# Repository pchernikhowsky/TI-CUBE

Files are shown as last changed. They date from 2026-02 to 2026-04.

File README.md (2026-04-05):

# The TI CUBE

The `TI CUBE` is a homebrew microcomputer I designed around the Texas Instruments TMS 9900 microprocessor and its associated peripheral devices.

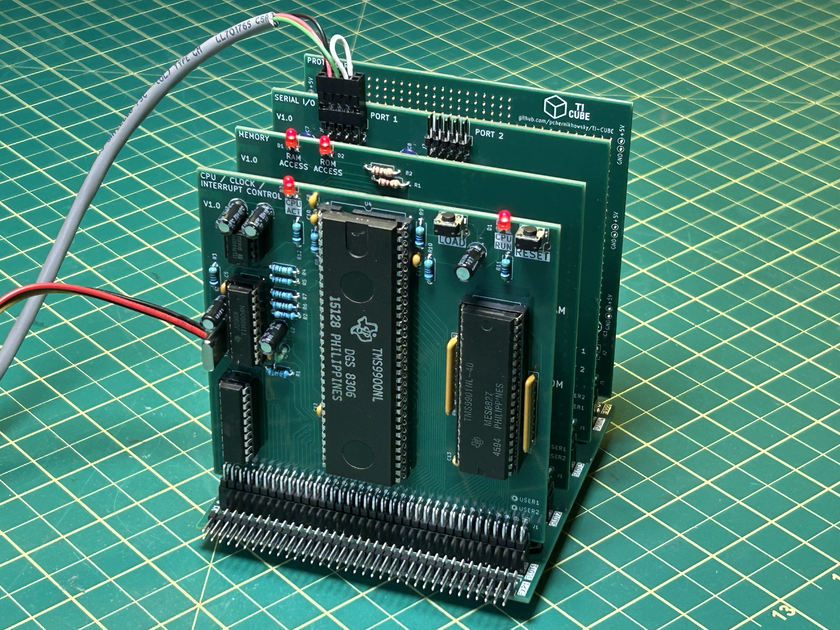
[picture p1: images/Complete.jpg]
Photo of the complete TI CUBE assembly


In its basic form the `TI CUBE` supports communications through two serial ports and has 32 KiB of ROM and 32 KiB of RAM for code and data storage.

# Why the TMS 9900?

The [TMS 9900 microprocessor was relatively advanced for its time (released in 1976)](https://www.cpushack.com/2015/02/05/ti-tms9900sbp9900-accidental-success/) and is essentially a single-chip version of TI's 990 series of 16-bit minicomputers from the 1970s. The TMS 9900 is considered one of the first true 16-bit microprocessors with a full 16-bit external data bus. This was allowed by the use of rather unconventional 64-pin DIP package. The address bus uses 15 bits, but since all memory accesses are 16-bits wide, this provides a 64 KiB address space (32 K of 16 bit words). The most unique feature of the TMS 9900 is that it had no internal registers, other than PC (program counter), WP (workspace pointer), and status register (SR) - all 16-bits wide. Instead of internal registers, the WP pointed to a region in external memory where 16 "registers" were stored in sequential memory addresses. Adjusting the WP allowed for very fast context switching by pointing to a different set of "registers". This capability was used in TI 990 minicomputers to support multiuser computing.

The elegance of the true 16-bit data bus (unlike the crippled Intel 8088 CPU used in the first IBM PC) and the quirkiness of its memory-based registers makes this chip a fascinating way to explore early microcomputer technology and its capabilities.

Finally, the project was greatly inspired by [Usagi Electric](https://www.youtube.com/@UsagiElectric)'s ongoing homebrew computer project based on the TMS 9900 CPU. I had a spare TMS 9900 IC that I removed from a TI-99/4A several decades ago(!), and figured this was a good way to put it to use. 

# Design Philosophy

The following principles guided my development of this homebrew project. The list is roughly in order of priority (highest is first).

1. **No 8-bit data buses!** The TMS 9900 microprocessor is fundamentally a 16-bit design descendent from TI's 990 series of 16-bit minicomputers and I wanted to honour this ancestry as much as possible. I find address/data bus muxing/demuxing unsightly, complex, and inelegant. Yes, the TMS 9900 isn't the fastest of the TMS 99XX series of microprocessors, but it's the only one that supports an *external* 16-bit data bus interface.

2. **Modularity.** Just like a minicomputer which would typically have a backplane populated with multiple cards, the `TI CUBE` uses a similar philosophy with three basic cards: 
   * CPU card (with clock and interrupt control)
   * Memory card (holding the RAM and ROM)
   * Serial port interface card (equipped with two serial chips driving two EIA-232C compatible ports). 
  
   All cards plug into a backplane using 72-pin header connectors. Any card can go in any slot, and multiple cards (e.g., multiple seial interface cards) are supported. Additional backplanes can also be daisy-chained to support additional card slots. The expansion connectors (especially the pin header connector) also makes for handy connections to bus signals for debugging (via a scope or logic analyzer).

3. **Board size.** Constraining the board size to 100 x 100 mm (4 x 4 in) allows ordering PCBs using the [JLCPCB](https://jlcpcb.com) or [PCBWAY](https://pcbway.com) prototyping services (personally, I have had great experience with JLCPCB). This significantly reduces the cost of individual boards (approximately $2 per board). The physical construction also gives the `TI CUBE` its name: four 100 x 100 mm vertical cards plugged into a horizontal four-slot 100 x 100 mm backplane.

4. **Simplicity.** I subscribe to the [Earl Muntz](https://en.wikipedia.org/wiki/Muntzing) philosophy. As such, the `TI CUBE` design uses the minimum required amount of components to accomplish its function. Random logic (i.e., TTL gates and decoders) is complex and consumes significant board space. Instead, I prefer to use simple and standard PLD devices like the ubiquitous 16V8, which does everything needed in one chip.[^4] This also allows easily reconfigurability simply by reprogramming the PLD. There are  no address or data buffers in the `TI CUBE`, but the small size combined with the use of four-layer PCBs keeps the digital signals clean; my builds have demonstrated excellent reliablity and performance. 

5. **Period correctness.** Primarily this means use of only through-hole components (no surface mount). I don't mind SMD as such, but through-hole is still easier to assemble and is more typical of 70s/80s computers. I have violated the period-correctness rule in number of other places (e.g., use of PLDs instead of random logic, larger memory ICs compared to what was available in the 70s and early 80s), so this one is more a [guideline than an actual rule](https://www.youtube.com/watch?v=omjnIeLIzJc&t=13s). 😉
   
8. **Compatibility.** I designed the `TI CUBE` to be generally compatible with other TMS 9900-based systems. One example is [Stuart Connor's TMS 9900 breadboard/PCB system](http://www.stuartconner.me.uk/tms9900_breadboard/tms9900_breadboard.htm). In fact, the binary files he provides can be downloaded, burned to EPROMs, and used directly in the `TI CUBE`. This includes the TIBUG monitor and Cortex BASIC which work right out of the box!

# Hardware Specifications

1. **CPU board** [(photo)](images/CPU.jpg)
-  TMS 9900 microprocessor running at 3 MHz[^1]
-  TIM 9904 or TIM 9904A clock generator[^2]
-  TMS 9901 programmable systems interface (PSI) for interrupt management
-  ATF16V8 PLD for address decoding
-  ICL7660 voltage convertor to generate the -5V power supply needed by the CPU
-  2x red LEDs for CPU RESET signal and CPU activity (driven by the IAQ output) indication
2. **Memory board** [(photo)](images/Memory.jpg)
-  2x EPROMs (e.g., 2764, 27128, 27256) for 32 KiB of EPROM[^3]
-  2x static RAM (e.g., 55256) for 32 KiB of RAM[^3]
-  2x red LEDs for RAM and ROM access indication
-  ATF16V8 PLD for address decoding
-  Jumpers to control use of the EPROM A14 address line (or to select the high or low bank)
3. **Serial I/O board** [(photo)](images/Serial_IO.jpg)
-  2x TMS 9902 asynchronous communications controllers (ACC)
-  2x MAX232 interfaces for EIA-232C compatible serial ports
-  2x ATF16V8 PLD for address decoding
-  2x 10-pin 0.1 in header connectors using the AT/Everex standard pinout to connect serial devices
-  Jumpers to allow address and interrupt selection for each TMS 9902
4. **Protoboard** [(photo)](images/Protoboard.jpg)
-  Unpopulated PCB with a large area of plated-through holes for prototyping
-  Optional ATF16V8 PLD for address decoding
5. **Backplane** [(photo)](images/Backplane.jpg)
-  4x 72-pin header sockets which support any combination of the cards above
-  1x 72-pin header socket for daisy chaining multiple backplanes
-  1x 72-pin header pin connector for daisy chaining multiple backplanes
-  2x red LEDs for +5V and +12 power supply indication
-  1x 4-pin Berg connector for +5V and +12V power supplies (compatible with a standard 3.5 in floppy power connector)

# Future Expansion/Ideas

## External Instructions
The TMS 9900 has an interesting feature where a handful of instructions can be decoded external and used to trigger various hardware functions. These instructions are:

## RAM Memory Expansion
The base system memory board decodes the entire address space of the TMS 9900, but this is a maximum of 65536 bytes (64 kiB). A number of other computers based on the TMS 9900 (e.g., Cortex and the TI 990/10 and 990/12) used memory mappers to expand the memory space up to 1 MiB or more of RAM. The primary advantage of this expansion is that would allow running either [MDEX](http://www.stuartconner.me.uk/mini_cortex/mini_cortex.htm#using_mdex) or [Unix](http://www.stuartconner.me.uk/mini_cortex/mini_cortex.htm#using_unix), both courtesy of Stuart Conner. I'd really like to try this as it might allow a rudimentary mulituser system when equipped with multiple additional serial cards. 

## Floppy and/or Hard Drive Controller

# Notes

[^1]: Overclocking to 4 MHz is possible if a TMS 9900-40 CPU is used and the appropriate clock component changes are made.

[^2]: Depending on whether the TIM 9904 or TIM 9904A is used, and which CPU frequency is desired (12 or 16 MHz) different components must be selected for the clock crystal and tank circuit. A table of values is provided in the CPU schematic.

[^3]: The RAM and ROM sizes can be adjusted in any combination that fits within the 64KB address space simply by adjusting the logic for the chip enable outputs in the PLD program.

[^4]: The use of PLDs does mean that you need a programmer (such as the [XGecu TL866II Plus](http://autoelectric.cn/EN/TL866_main.html), or similar). What, you don't have one? Then get one - they're super handy for retrocomputing.

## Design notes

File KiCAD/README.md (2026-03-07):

# TI Cube schematics and PCB design files

These folders contain the schematic and PCB design files for the four cards and backplane.

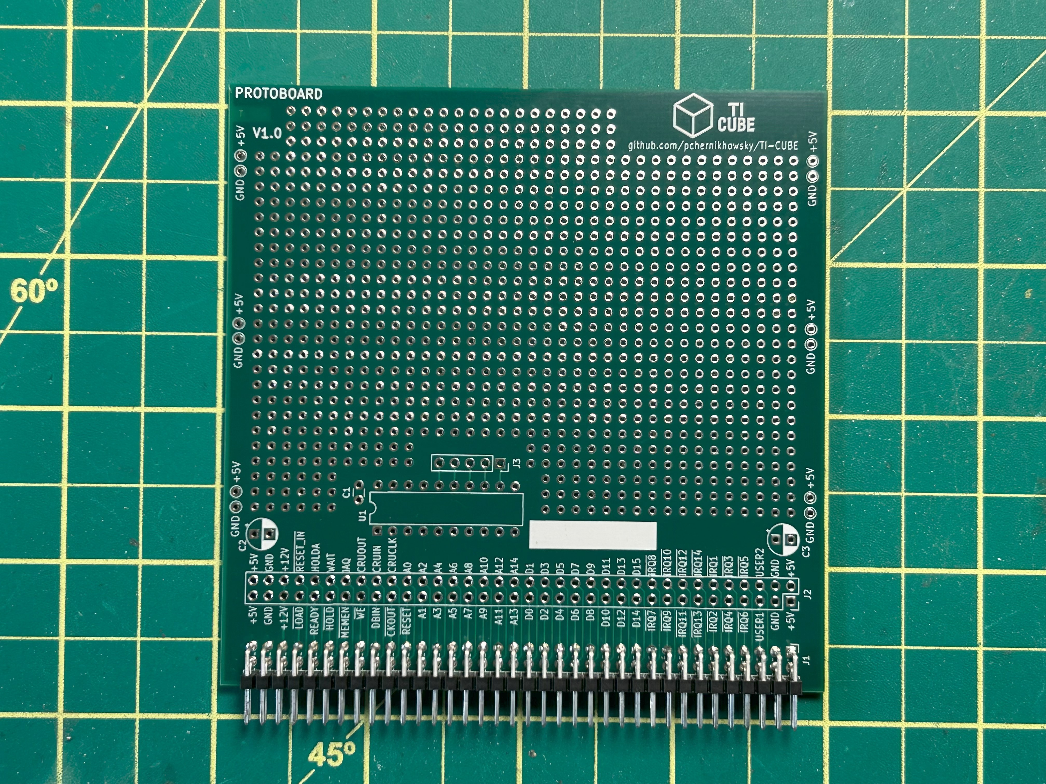
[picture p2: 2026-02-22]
images/Protoboard.jpg

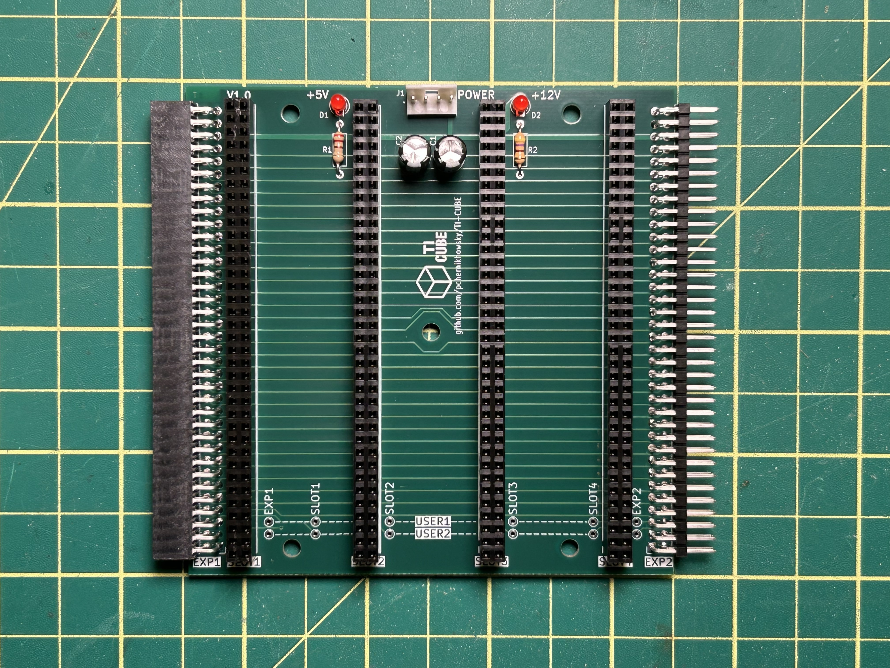
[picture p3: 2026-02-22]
images/Backplane.jpg

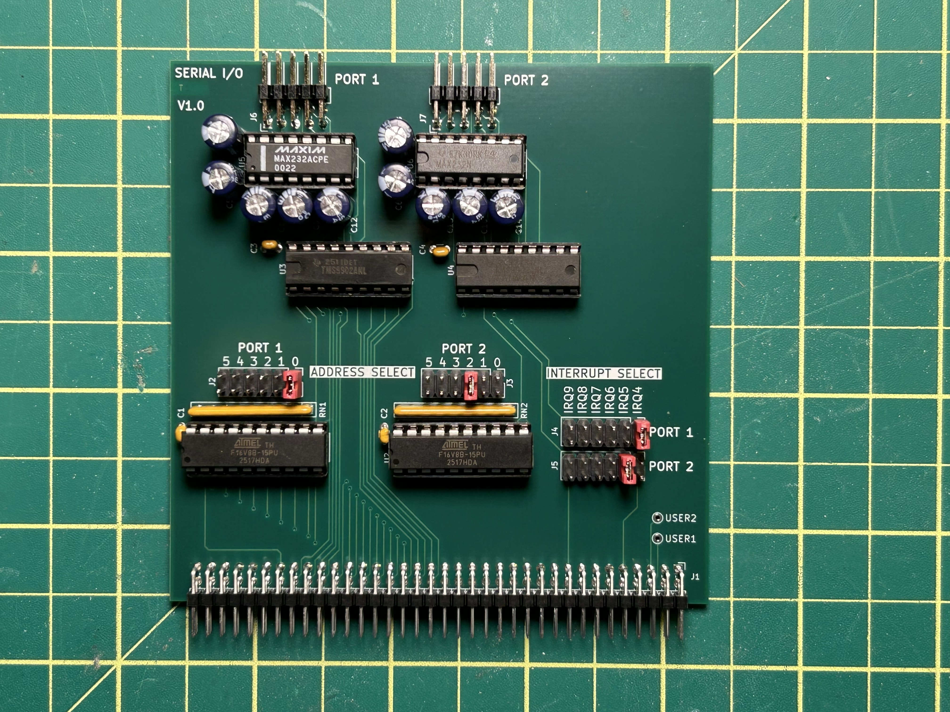
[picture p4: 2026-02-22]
images/Serial_IO.jpg

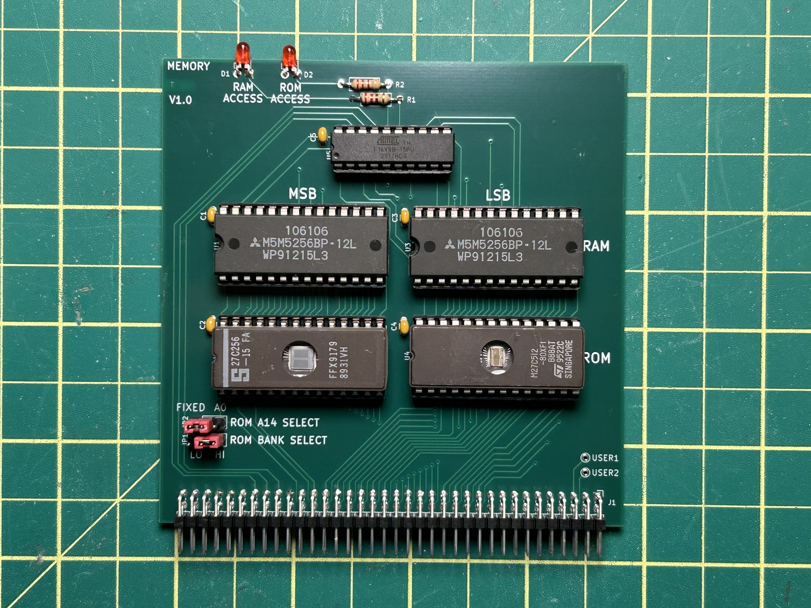
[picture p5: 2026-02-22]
images/Memory.jpg

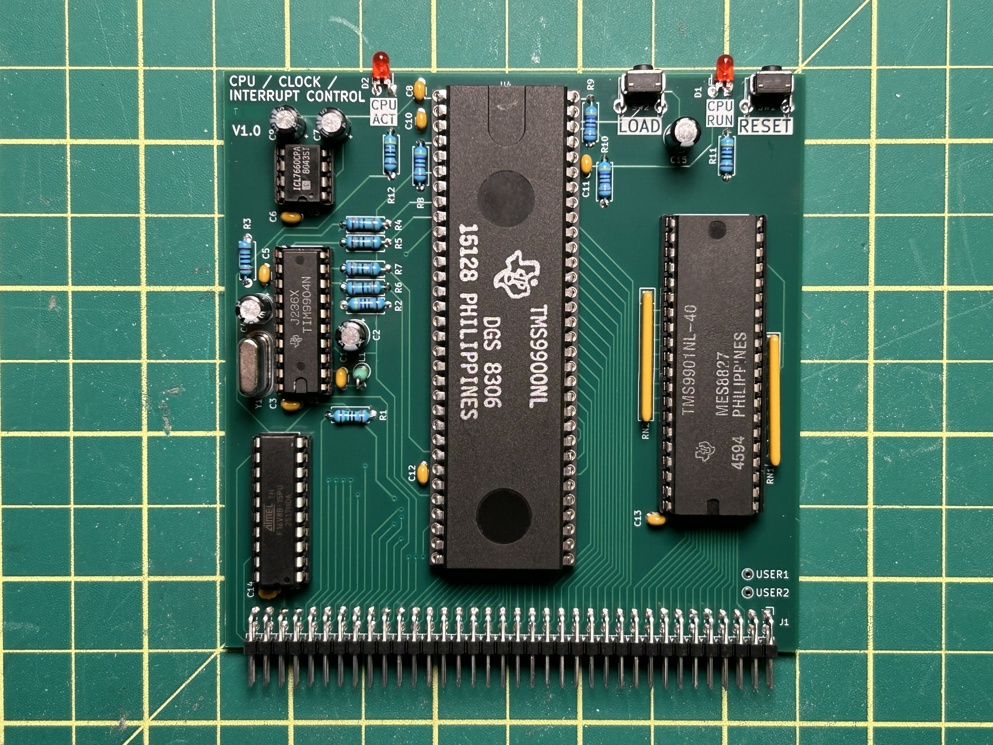
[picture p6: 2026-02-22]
images/CPU.jpg

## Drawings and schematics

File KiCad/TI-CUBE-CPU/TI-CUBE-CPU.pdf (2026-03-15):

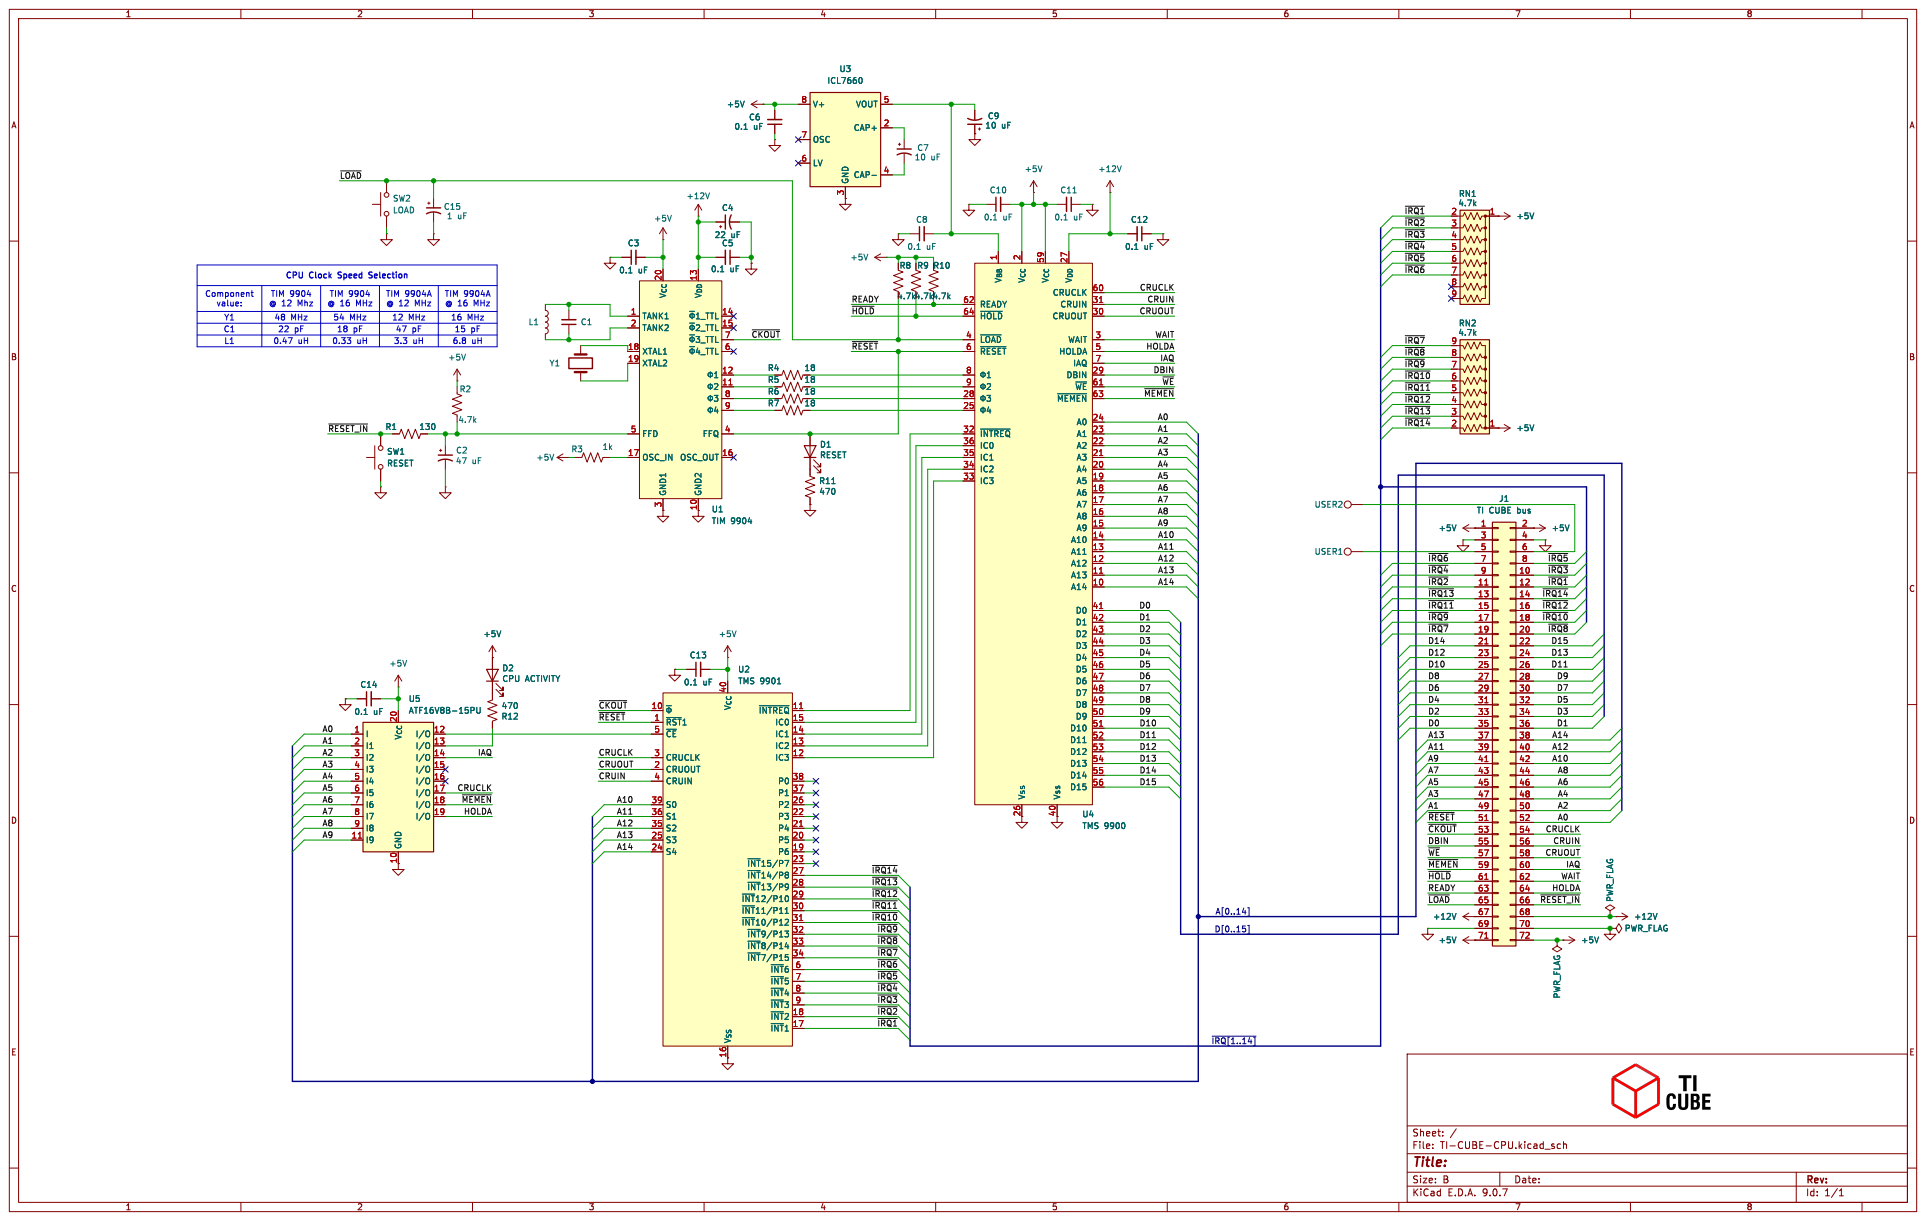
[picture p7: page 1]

Id: 1/1 Title: File: TI-CUBE-CPU.kicad_sch Sheet: /

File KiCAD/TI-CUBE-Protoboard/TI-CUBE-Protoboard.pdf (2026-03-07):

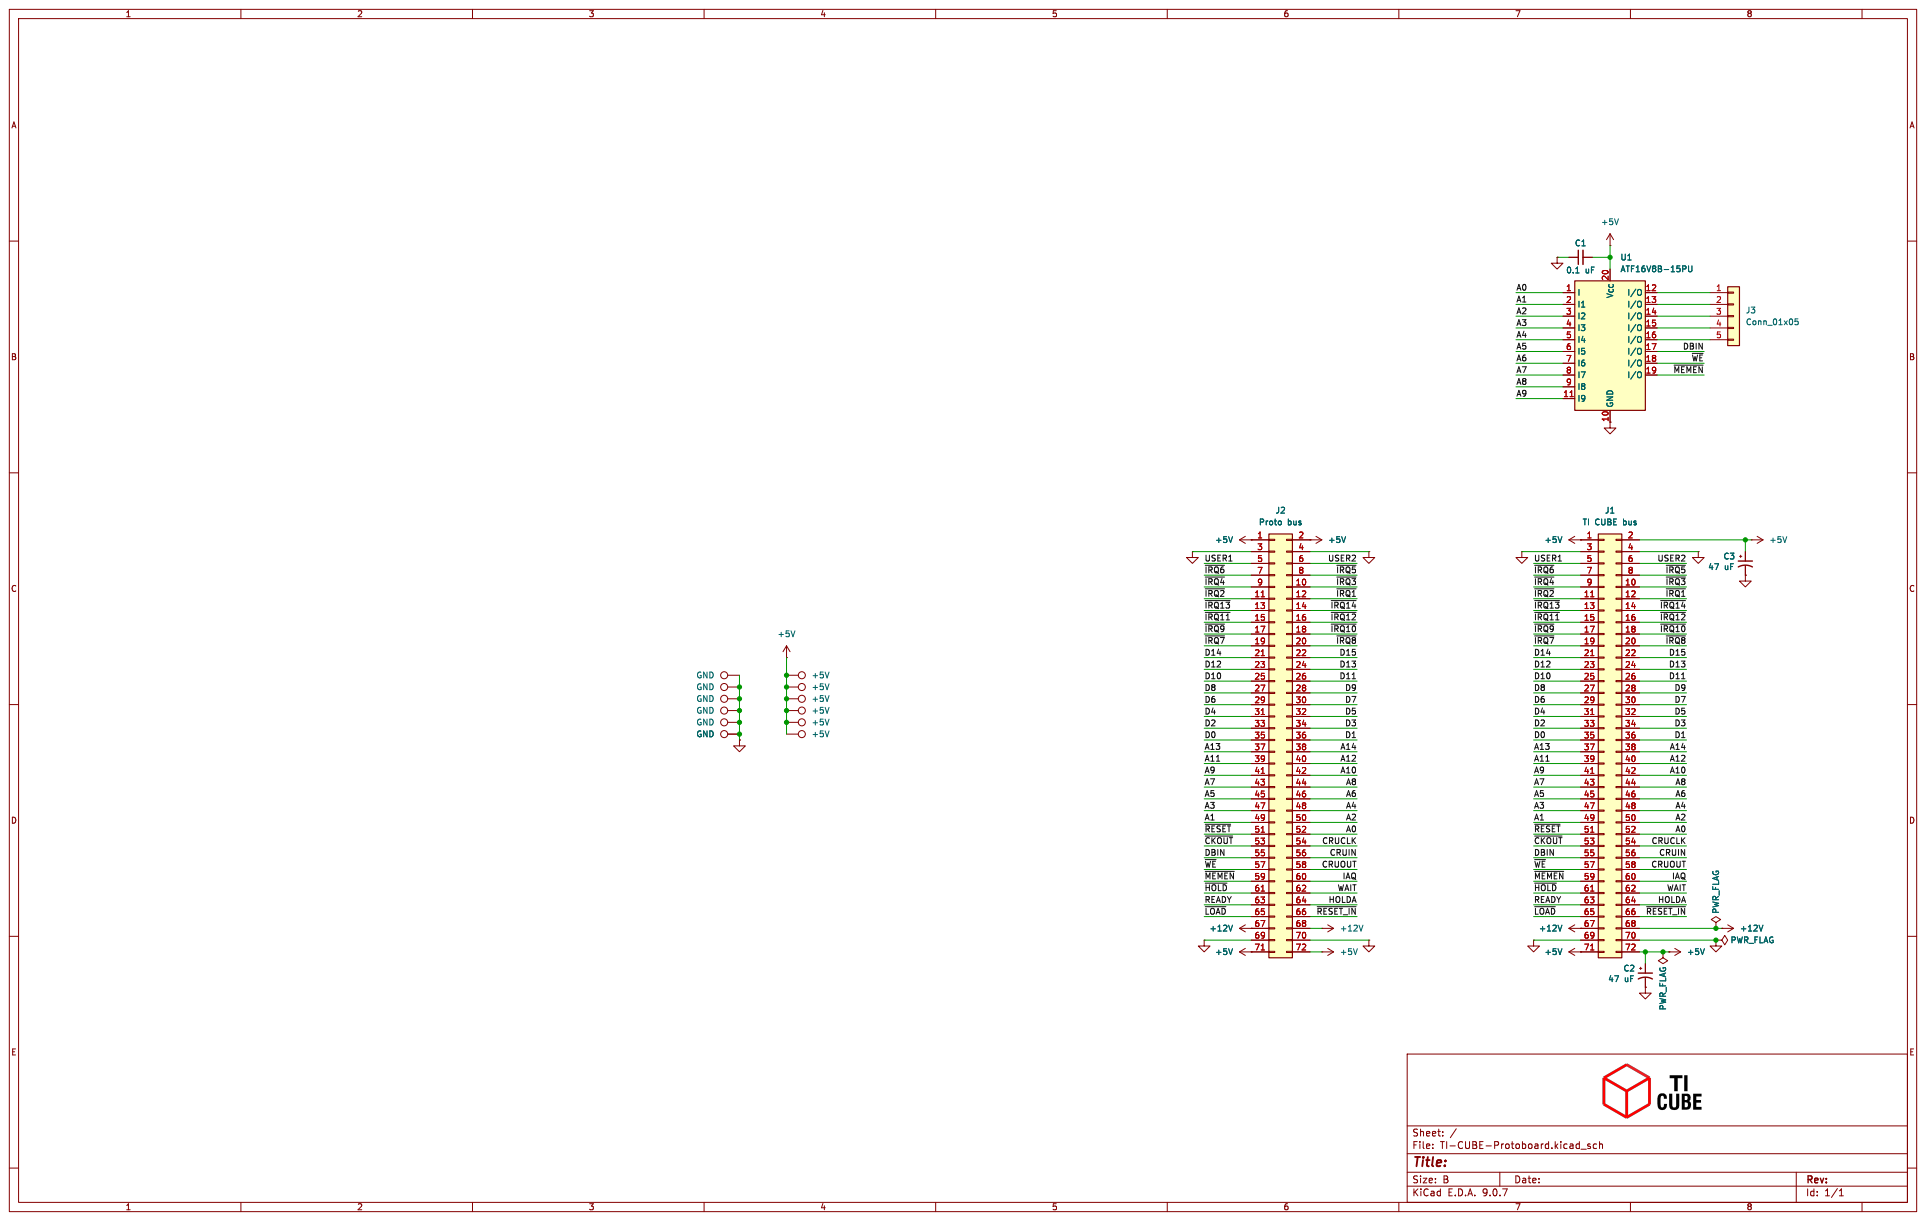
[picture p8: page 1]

Id: 1/1 Title: File: TI-CUBE-Protoboard.kicad_sch Sheet: / GND

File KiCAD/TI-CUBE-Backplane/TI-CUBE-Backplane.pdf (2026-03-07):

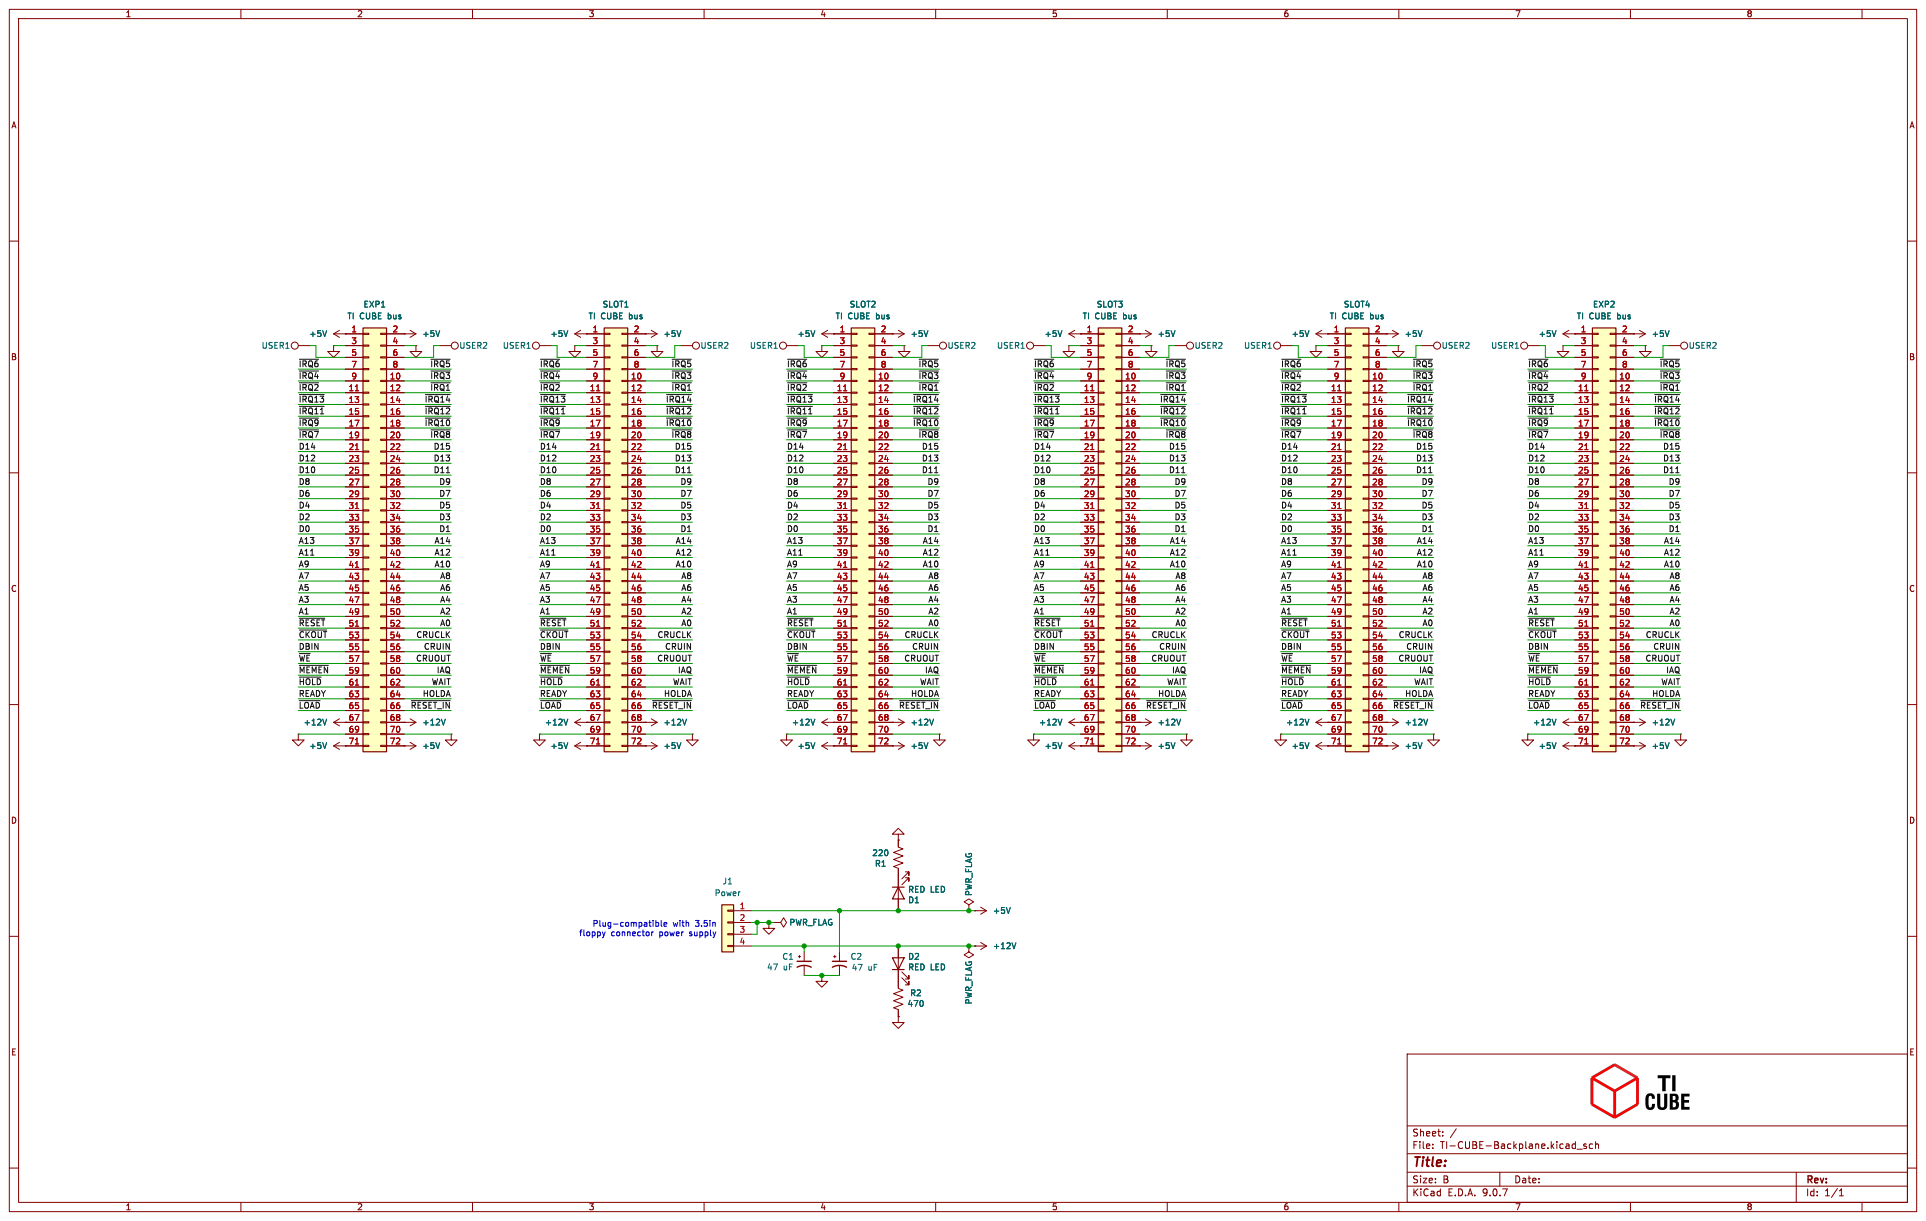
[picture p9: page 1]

Id: 1/1 Title: File: TI-CUBE-Backplane.kicad_sch Sheet: / C1

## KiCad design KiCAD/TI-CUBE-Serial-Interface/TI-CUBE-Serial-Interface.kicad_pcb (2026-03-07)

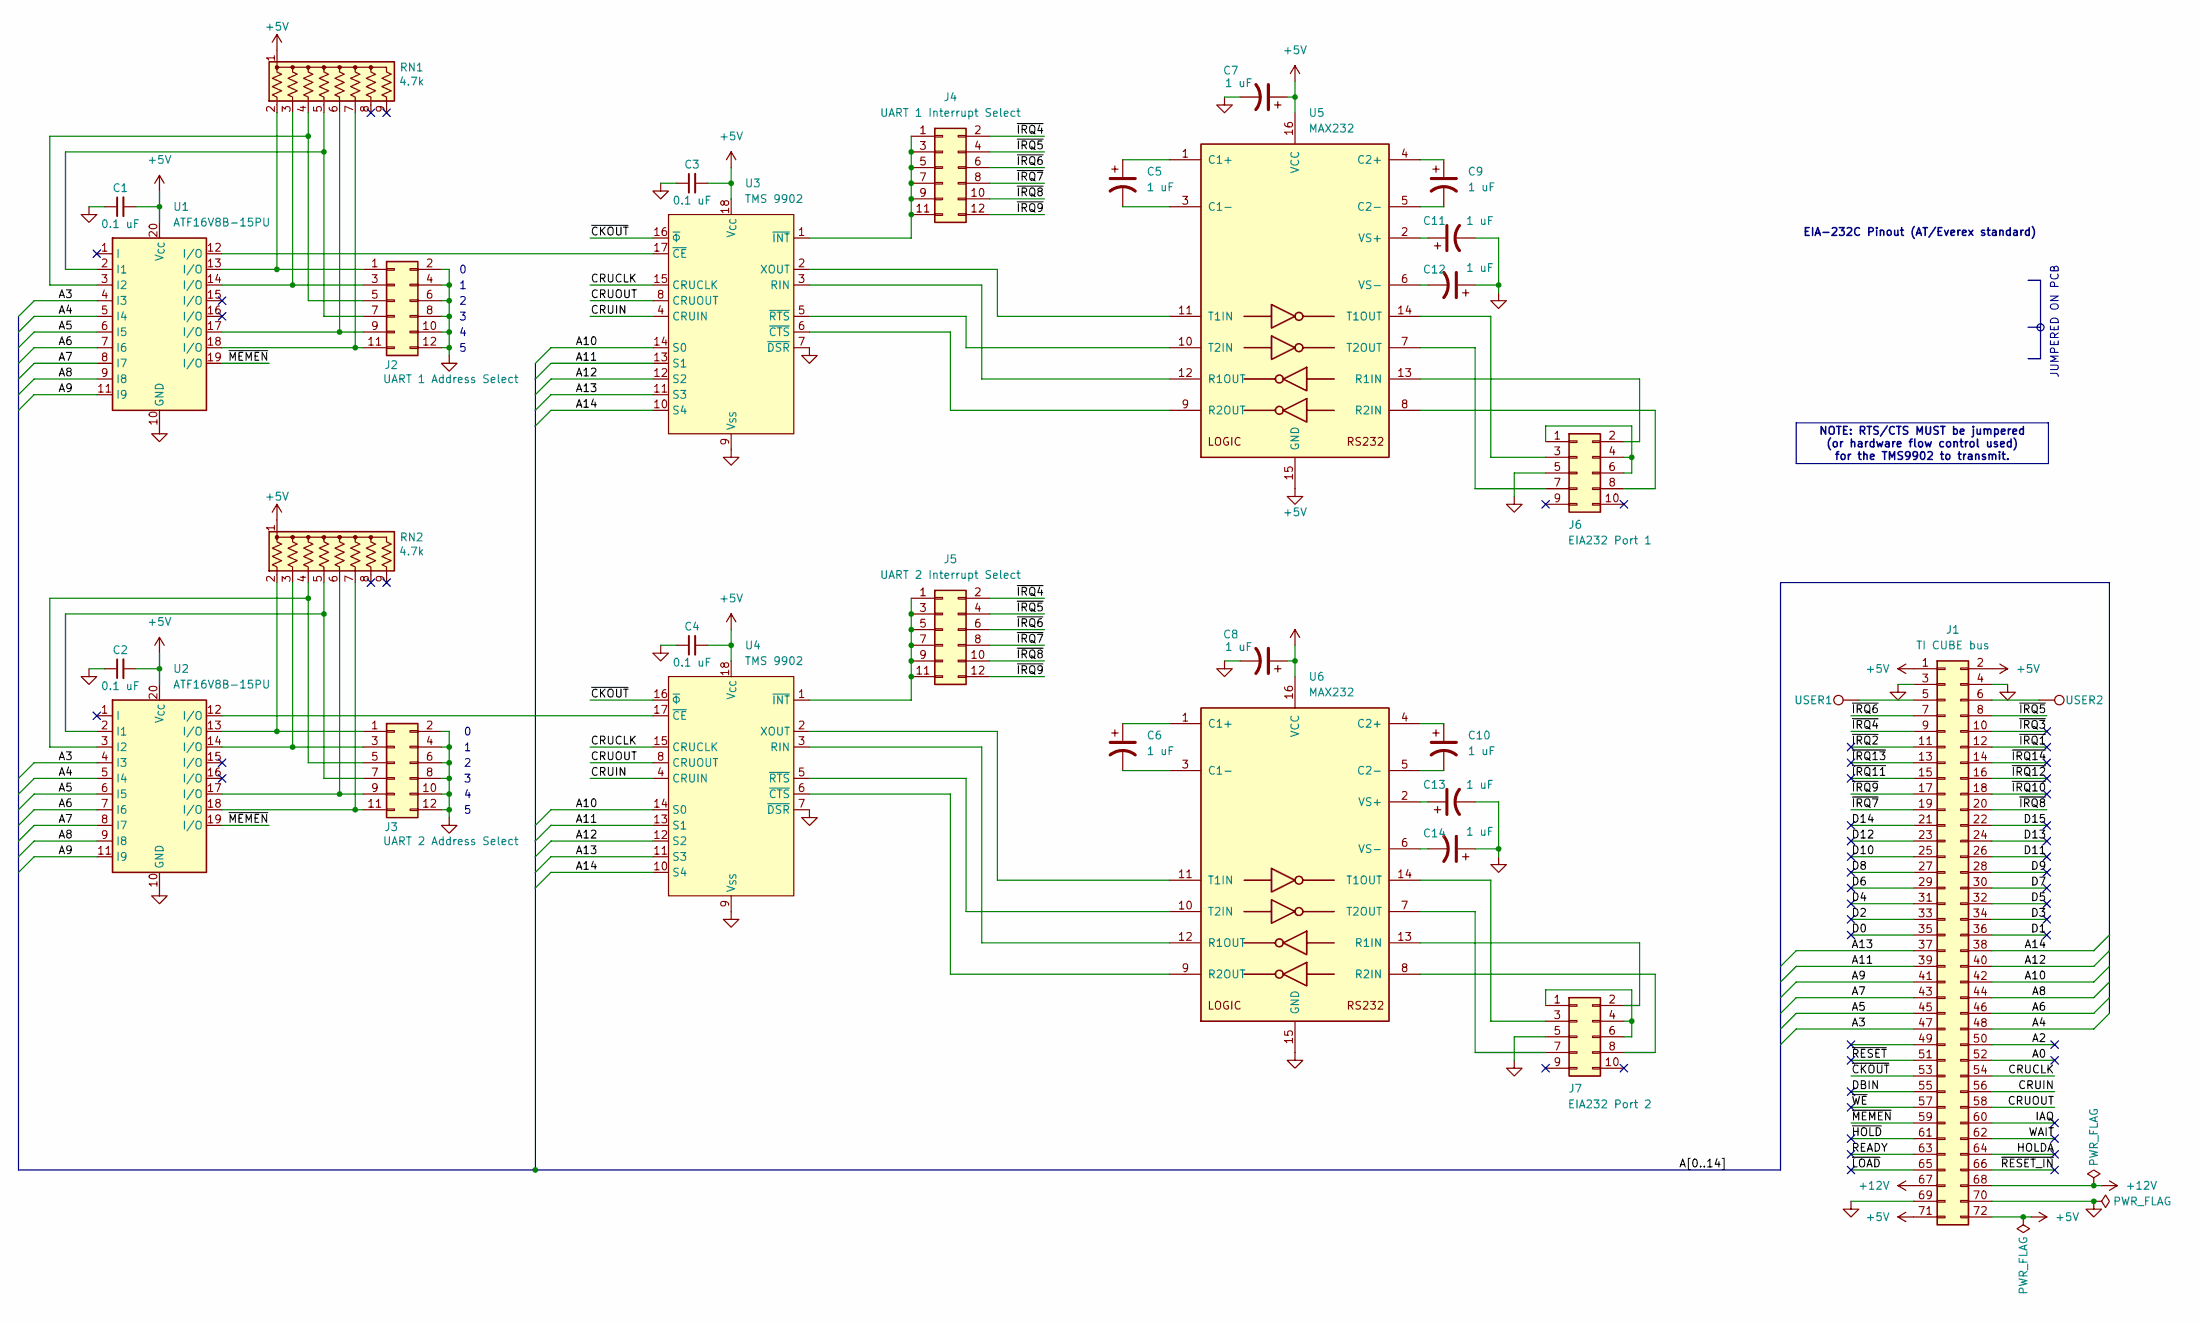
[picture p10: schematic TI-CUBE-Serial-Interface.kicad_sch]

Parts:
C1, C2, C3, C4: 0.1 uF; C_Ceramic_Cap_P2.50mm
C5, C6, C7, C8, C9, C10, C11, C12, C13, C14: 1 uF; CP_Radial_D5.0mm_P2.50mm
J1: TI CUBE bus; PinHeader_2x36_P2.54mm_Horizontal
J2: UART 1 Address Select; PinHeader_2x06_P2.54mm_Vertical
J3: UART 2 Address Select; PinHeader_2x06_P2.54mm_Vertical
J4: UART 1 Interrupt Select; PinHeader_2x06_P2.54mm_Vertical
J5: UART 2 Interrupt Select; PinHeader_2x06_P2.54mm_Vertical
J6: EIA232 Port 1; PinHeader_2x05_P2.54mm_Horizontal
J7: EIA232 Port 2; PinHeader_2x05_P2.54mm_Horizontal
RN1, RN2: 4.7k; R_Array_SIP9
U1, U2: ATF16V8B-15PU; DIP-20_W7.62mm
U3, U4: TMS 9902; DIP-18_W7.62mm
U5, U6: MAX232; DIP-16_W7.62mm
USER1: USER2; TestPoint_THTPad_D1.5mm_Drill0.7mm
USER2: USER1; TestPoint_THTPad_D1.5mm_Drill0.7mm

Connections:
+5V: C1.2, C2.2, C3.2, C4.2, C7.1, C8.1, J1.1, J1.2, J1.71, J1.72, RN1.1 (common), RN2.1 (common), U1.20 (V_{CC}), U2.20 (V_{CC}), U3.18 (V_{CC}), U4.18 (V_{CC}), U5.16 (VCC), U6.16 (VCC)
+12V: J1.67, J1.68
/A0: J1.52
/A2: J1.50
/A3: J1.47, U1.4 (I3), U2.4 (I3)
/A4: J1.48, U1.5 (I4), U2.5 (I4)
/A5: J1.45, U1.6 (I5), U2.6 (I5)
/A6: J1.46, U1.7 (I6), U2.7 (I6)
/A7: J1.43, U1.8 (I7), U2.8 (I7)
/A8: J1.44, U1.9 (I8), U2.9 (I8)
/A9: J1.41, U1.11 (I9), U2.11 (I9)
/A10: J1.42, U3.14 (S0), U4.14 (S0)
/A11: J1.39, U3.13 (S1), U4.13 (S1)
/A12: J1.40, U3.12 (S2), U4.12 (S2)
/A13: J1.37, U3.11 (S3), U4.11 (S3)
/A14: J1.38, U3.10 (S4), U4.10 (S4)
/CRUCLK: J1.54, U3.15 (CRUCLK), U4.15 (CRUCLK)
/CRUIN: J1.56, U3.4 (CRUIN), U4.4 (CRUIN)
/CRUOUT: J1.58, U3.8 (CRUOUT), U4.8 (CRUOUT)
/D0: J1.35
/D1: J1.36
/D2: J1.33
/D3: J1.34
/D4: J1.31
/D5: J1.32
/D6: J1.29
/D7: J1.30
/D8: J1.27
/D9: J1.28
/D10: J1.25
/D11: J1.26
/D12: J1.23
/D13: J1.24
/D14: J1.21
/D15: J1.22
/DBIN: J1.55
/HOLDA: J1.64
/IAQ: J1.60
/READY: J1.63
/WAIT: J1.62
/~CKOUT: J1.53, U3.16 (~Φ), U4.16 (~Φ)
/~HOLD: J1.61
/~IRQ1: J1.12
/~IRQ2: J1.11
/~IRQ3: J1.10
/~IRQ4: J1.9, J4.2, J5.2
/~IRQ5: J1.8, J4.4, J5.4
/~IRQ6: J1.7, J4.6, J5.6
/~IRQ7: J1.19, J4.8, J5.8
/~IRQ8: J1.20, J4.10, J5.10
/~IRQ9: J1.17, J4.12, J5.12
/~IRQ10: J1.18
/~IRQ11: J1.15
/~IRQ12: J1.16
/~IRQ13: J1.13
/~IRQ14: J1.14
/~LOAD: J1.65
/~MEMEN: J1.59, U1.19 (I/O), U2.19 (I/O)
/~RESET_IN: J1.66
/~RESET: J1.51
/~WE: J1.57
GND: C1.1, C2.1, C3.1, C4.1, C7.2, C8.2, C11.2, C12.1, C13.2, C14.1, J1.3, J1.4, J1.69, J1.70, J2.2, J2.4, J2.6, J2.8, J2.10, J2.12, J3.2, J3.4, J3.6, J3.8, J3.10, J3.12, J6.5, J7.5, U1.10 (GND), U2.10 (GND), U3.7 (~DSR), U3.9 (V_{SS}), U4.7 (~DSR), U4.9 (V_{SS}), U5.15 (GND), U6.15 (GND)
unnamed: J1.5, USER2.1
unnamed: J1.6, USER1.1
unnamed: J2.1, RN1.2 (R1), U1.13 (I/O)
unnamed: J2.3, RN1.3 (R2), U1.14 (I/O)
unnamed: J2.5, RN1.4 (R3), U1.3 (I2)
unnamed: J2.7, RN1.5 (R4), U1.2 (I1)
unnamed: J2.9, RN1.6 (R5), U1.17 (I/O)
unnamed: J2.11, RN1.7 (R6), U1.18 (I/O)
unnamed: J3.1, RN2.2 (R1), U2.13 (I/O)
unnamed: J3.3, RN2.3 (R2), U2.14 (I/O)
unnamed: J3.5, RN2.4 (R3), U2.3 (I2)
unnamed: J3.7, RN2.5 (R4), U2.2 (I1)
unnamed: J3.9, RN2.6 (R5), U2.17 (I/O)
unnamed: J3.11, RN2.7 (R6), U2.18 (I/O)
unnamed: J4.1, J4.3, J4.5, J4.7, J4.9, J4.11, U3.1 (~INT)
unnamed: J5.1, J5.3, J5.5, J5.7, J5.9, J5.11, U4.1 (~INT)
unnamed: J6.1, J6.4, J6.6
unnamed: J6.2, U5.13 (R1IN)
unnamed: J6.3, U5.14 (T1OUT)
unnamed: J6.7, U5.7 (T2OUT)
unnamed: J6.8, U5.8 (R2IN)
unnamed: J7.1, J7.4, J7.6
unnamed: J7.2, U6.13 (R1IN)
unnamed: J7.3, U6.14 (T1OUT)
unnamed: J7.7, U6.7 (T2OUT)
unnamed: J7.8, U6.8 (R2IN)
unnamed: U3.3 (RIN), U5.12 (R1OUT)
unnamed: U3.2 (XOUT), U5.11 (T1IN)
unnamed: U1.12 (I/O), U3.17 (~CE)
unnamed: U3.6 (~CTS), U5.9 (R2OUT)
unnamed: U3.5 (~RTS), U5.10 (T2IN)
unnamed: U4.3 (RIN), U6.12 (R1OUT)
unnamed: U4.2 (XOUT), U6.11 (T1IN)
unnamed: U2.12 (I/O), U4.17 (~CE)
unnamed: U4.6 (~CTS), U6.9 (R2OUT)
unnamed: U4.5 (~RTS), U6.10 (T2IN)
unnamed: C5.1, U5.1 (C1+)
unnamed: C5.2, U5.3 (C1-)
unnamed: C9.1, U5.4 (C2+)
unnamed: C9.2, U5.5 (C2-)
unnamed: C11.1, U5.2 (VS+)
unnamed: C12.2, U5.6 (VS-)
unnamed: C6.1, U6.1 (C1+)
unnamed: C6.2, U6.3 (C1-)
unnamed: C10.1, U6.4 (C2+)
unnamed: C10.2, U6.5 (C2-)
unnamed: C13.1, U6.2 (VS+)
unnamed: C14.2, U6.6 (VS-)

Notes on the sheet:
JUMPERED ON PCB
EIA-232C Pinout (AT/Everex standard)
NOTE: RTS/CTS MUST be jumpered (or hardware flow control used) for the TMS9902 to transmit.

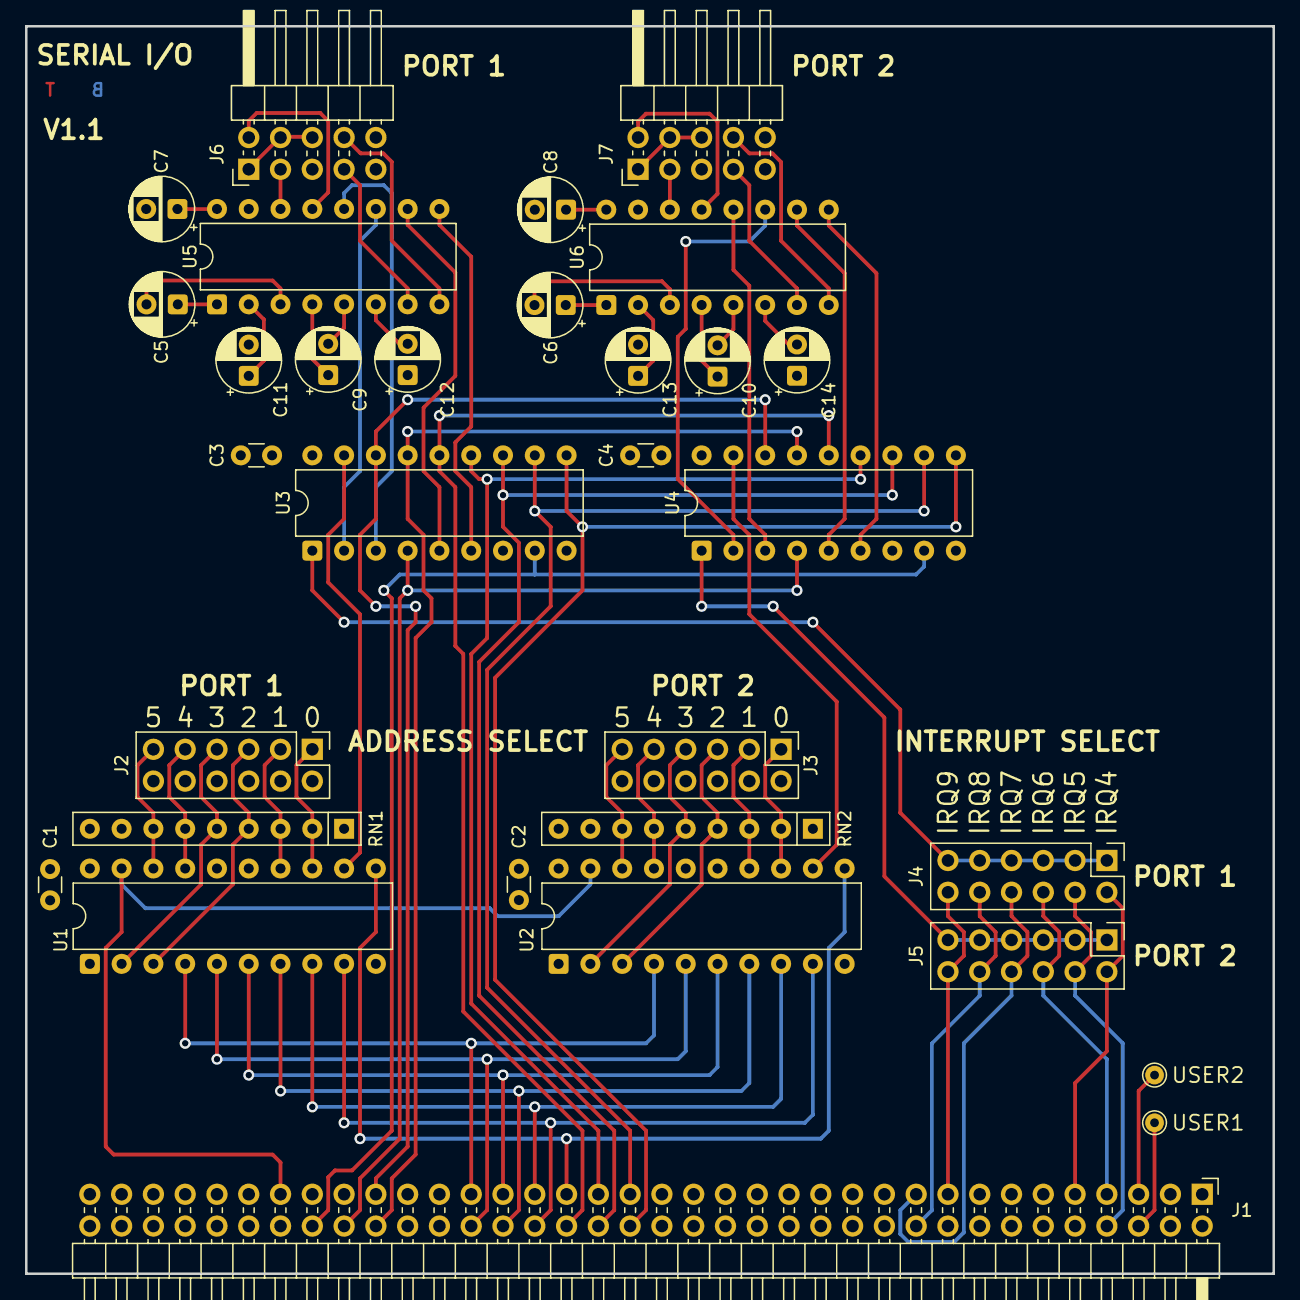
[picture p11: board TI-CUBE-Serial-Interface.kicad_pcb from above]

Board: 4 copper layers, 99.7 x 99.7 mm, 31 parts (0 on the bottom side), 74 nets.

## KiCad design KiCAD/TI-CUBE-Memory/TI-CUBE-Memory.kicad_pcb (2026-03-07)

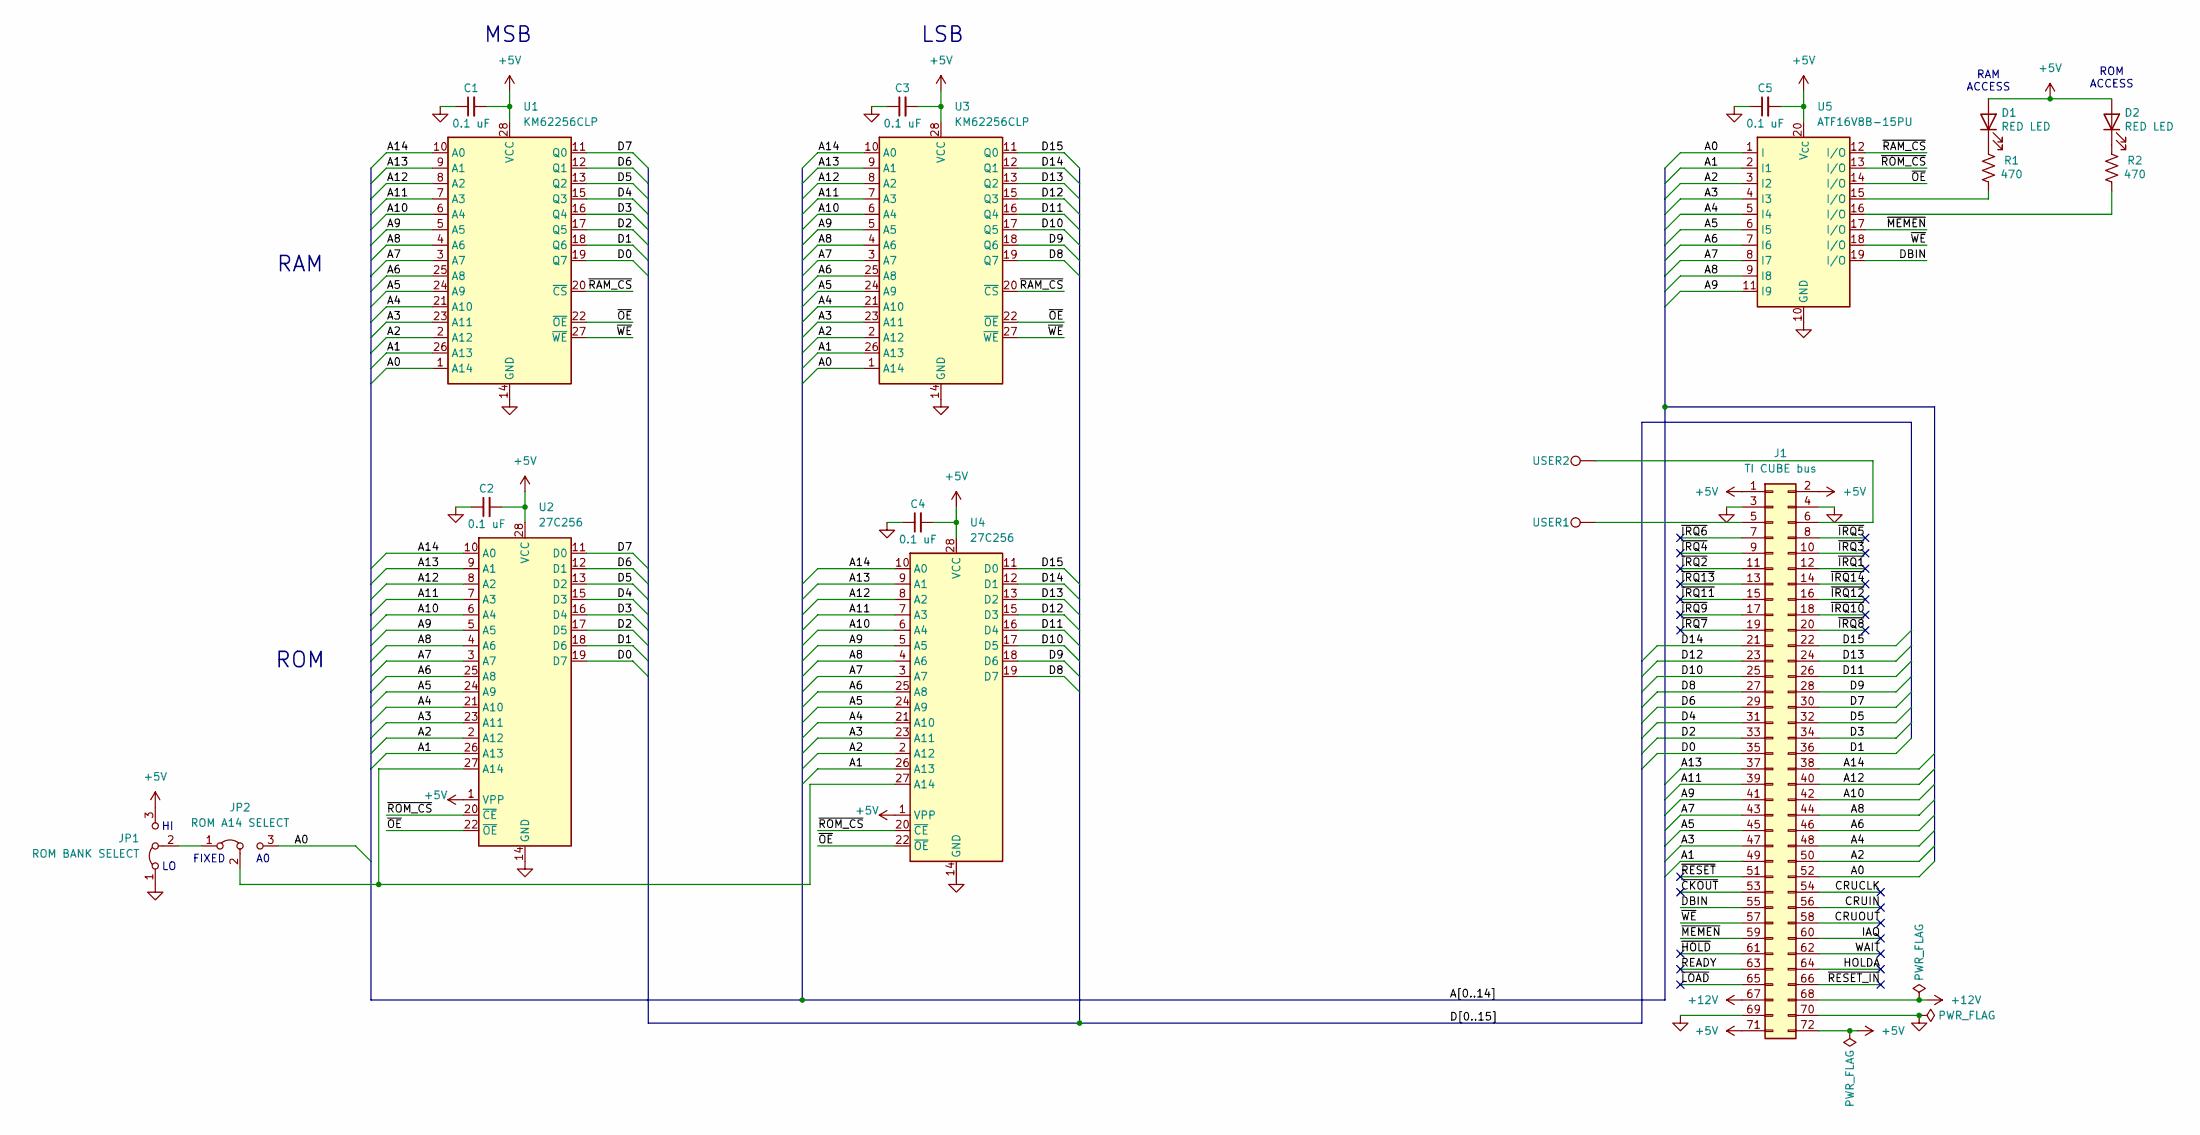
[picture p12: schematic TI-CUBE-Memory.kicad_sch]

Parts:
C1, C2, C3, C4, C5: 0.1 uF; C_Ceramic_Cap_P2.50mm
D1, D2: RED LED; LED_D3.0mm_Horizontal_O1.27mm_Z2.0mm
J1: TI CUBE bus; PinHeader_2x36_P2.54mm_Horizontal
JP1: ROM BANK SELECT; PinHeader_1x03_P2.54mm_Vertical
JP2: ROM A14 SELECT; PinHeader_1x03_P2.54mm_Vertical
R1, R2: 470; R_Axial_DIN0207_L6.3mm_D2.5mm_P10.16mm_Horizontal
U1, U3: KM62256CLP; DIP-28_W15.24mm
U2, U4: 27C256; DIP-28_W15.24mm
U5: ATF16V8B-15PU; DIP-20_W7.62mm
USER1: USER1; TestPoint_THTPad_D1.5mm_Drill0.7mm
USER2: USER2; TestPoint_THTPad_D1.5mm_Drill0.7mm

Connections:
+5V: C1.2, C2.2, C3.2, C4.2, C5.2, D1.2 (A), D2.2 (A), J1.1, J1.2, J1.71, J1.72, JP1.3 (B), U1.28 (VCC), U2.1 (VPP), U2.28 (VCC), U3.28 (VCC), U4.1 (VPP), U4.28 (VCC), U5.20 (V_{CC})
+12V: J1.67, J1.68
/A0: J1.52, JP2.3 (B), U1.1 (A14), U3.1 (A14), U5.1 (I)
/A1: J1.49, U1.26 (A13), U2.26 (A13), U3.26 (A13), U4.26 (A13), U5.2 (I1)
/A2: J1.50, U1.2 (A12), U2.2 (A12), U3.2 (A12), U4.2 (A12), U5.3 (I2)
/A3: J1.47, U1.23 (A11), U2.23 (A11), U3.23 (A11), U4.23 (A11), U5.4 (I3)
/A4: J1.48, U1.21 (A10), U2.21 (A10), U3.21 (A10), U4.21 (A10), U5.5 (I4)
/A5: J1.45, U1.24 (A9), U2.24 (A9), U3.24 (A9), U4.24 (A9), U5.6 (I5)
/A6: J1.46, U1.25 (A8), U2.25 (A8), U3.25 (A8), U4.25 (A8), U5.7 (I6)
/A7: J1.43, U1.3 (A7), U2.3 (A7), U3.3 (A7), U4.3 (A7), U5.8 (I7)
/A8: J1.44, U1.4 (A6), U2.4 (A6), U3.4 (A6), U4.4 (A6), U5.9 (I8)
/A9: J1.41, U1.5 (A5), U2.5 (A5), U3.5 (A5), U4.5 (A5), U5.11 (I9)
/A10: J1.42, U1.6 (A4), U2.6 (A4), U3.6 (A4), U4.6 (A4)
/A11: J1.39, U1.7 (A3), U2.7 (A3), U3.7 (A3), U4.7 (A3)
/A12: J1.40, U1.8 (A2), U2.8 (A2), U3.8 (A2), U4.8 (A2)
/A13: J1.37, U1.9 (A1), U2.9 (A1), U3.9 (A1), U4.9 (A1)
/A14: J1.38, U1.10 (A0), U2.10 (A0), U3.10 (A0), U4.10 (A0)
/CRUCLK: J1.54
/CRUIN: J1.56
/CRUOUT: J1.58
/D0: J1.35, U1.19 (Q7), U2.19 (D7)
/D1: J1.36, U1.18 (Q6), U2.18 (D6)
/D2: J1.33, U1.17 (Q5), U2.17 (D5)
/D3: J1.34, U1.16 (Q4), U2.16 (D4)
/D4: J1.31, U1.15 (Q3), U2.15 (D3)
/D5: J1.32, U1.13 (Q2), U2.13 (D2)
/D6: J1.29, U1.12 (Q1), U2.12 (D1)
/D7: J1.30, U1.11 (Q0), U2.11 (D0)
/D8: J1.27, U3.19 (Q7), U4.19 (D7)
/D9: J1.28, U3.18 (Q6), U4.18 (D6)
/D10: J1.25, U3.17 (Q5), U4.17 (D5)
/D11: J1.26, U3.16 (Q4), U4.16 (D4)
/D12: J1.23, U3.15 (Q3), U4.15 (D3)
/D13: J1.24, U3.13 (Q2), U4.13 (D2)
/D14: J1.21, U3.12 (Q1), U4.12 (D1)
/D15: J1.22, U3.11 (Q0), U4.11 (D0)
/DBIN: J1.55, U5.19 (I/O)
/HOLDA: J1.64
/IAQ: J1.60
/READY: J1.63
/WAIT: J1.62
/~CKOUT: J1.53
/~HOLD: J1.61
/~IRQ1: J1.12
/~IRQ2: J1.11
/~IRQ3: J1.10
/~IRQ4: J1.9
/~IRQ5: J1.8
/~IRQ6: J1.7
/~IRQ7: J1.19
/~IRQ8: J1.20
/~IRQ9: J1.17
/~IRQ10: J1.18
/~IRQ11: J1.15
/~IRQ12: J1.16
/~IRQ13: J1.13
/~IRQ14: J1.14
/~LOAD: J1.65
/~MEMEN: J1.59, U5.17 (I/O)
/~OE: U1.22 (~OE), U2.22 (~OE), U3.22 (~OE), U4.22 (~OE), U5.14 (I/O)
/~RAM_CS: U1.20 (~CS), U3.20 (~CS), U5.12 (I/O)
/~RESET_IN: J1.66
/~RESET: J1.51
/~ROM_CS: U2.20 (~CE), U4.20 (~CE), U5.13 (I/O)
/~WE: J1.57, U1.27 (~WE), U3.27 (~WE), U5.18 (I/O)
GND: C1.1, C2.1, C3.1, C4.1, C5.1, J1.3, J1.4, J1.69, J1.70, JP1.1 (A), U1.14 (GND), U2.14 (GND), U3.14 (GND), U4.14 (GND), U5.10 (GND)
unnamed: D1.1 (K), R1.2
unnamed: D2.1 (K), R2.2
unnamed: J1.5, USER1.1
unnamed: J1.6, USER2.1
unnamed: JP1.2 (C), JP2.1 (A)
unnamed: JP2.2 (C), U2.27 (A14), U4.27 (A14)
unnamed: R1.1, U5.15 (I/O)
unnamed: R2.1, U5.16 (I/O)

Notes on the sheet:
ROM
RAM
FIXED
MSB
RAM ACCESS
LSB
ROM ACCESS

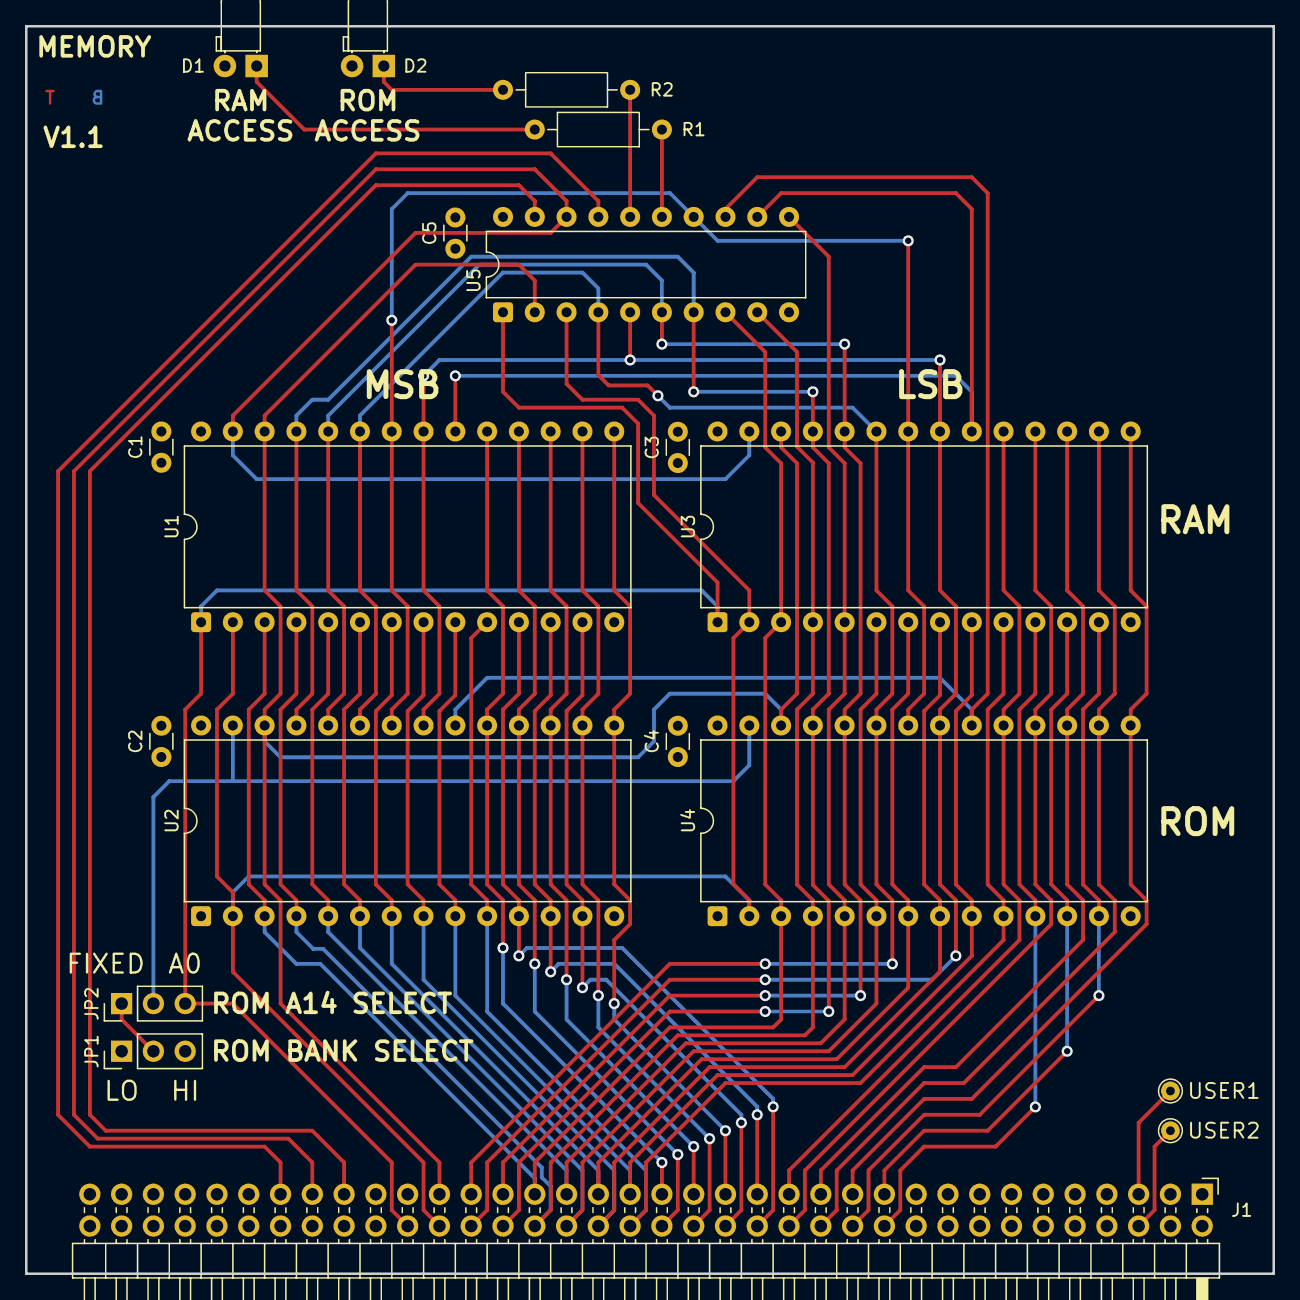
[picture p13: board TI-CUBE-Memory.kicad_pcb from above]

Board: 4 copper layers, 99.7 x 99.7 mm, 19 parts (0 on the bottom side), 48 nets.

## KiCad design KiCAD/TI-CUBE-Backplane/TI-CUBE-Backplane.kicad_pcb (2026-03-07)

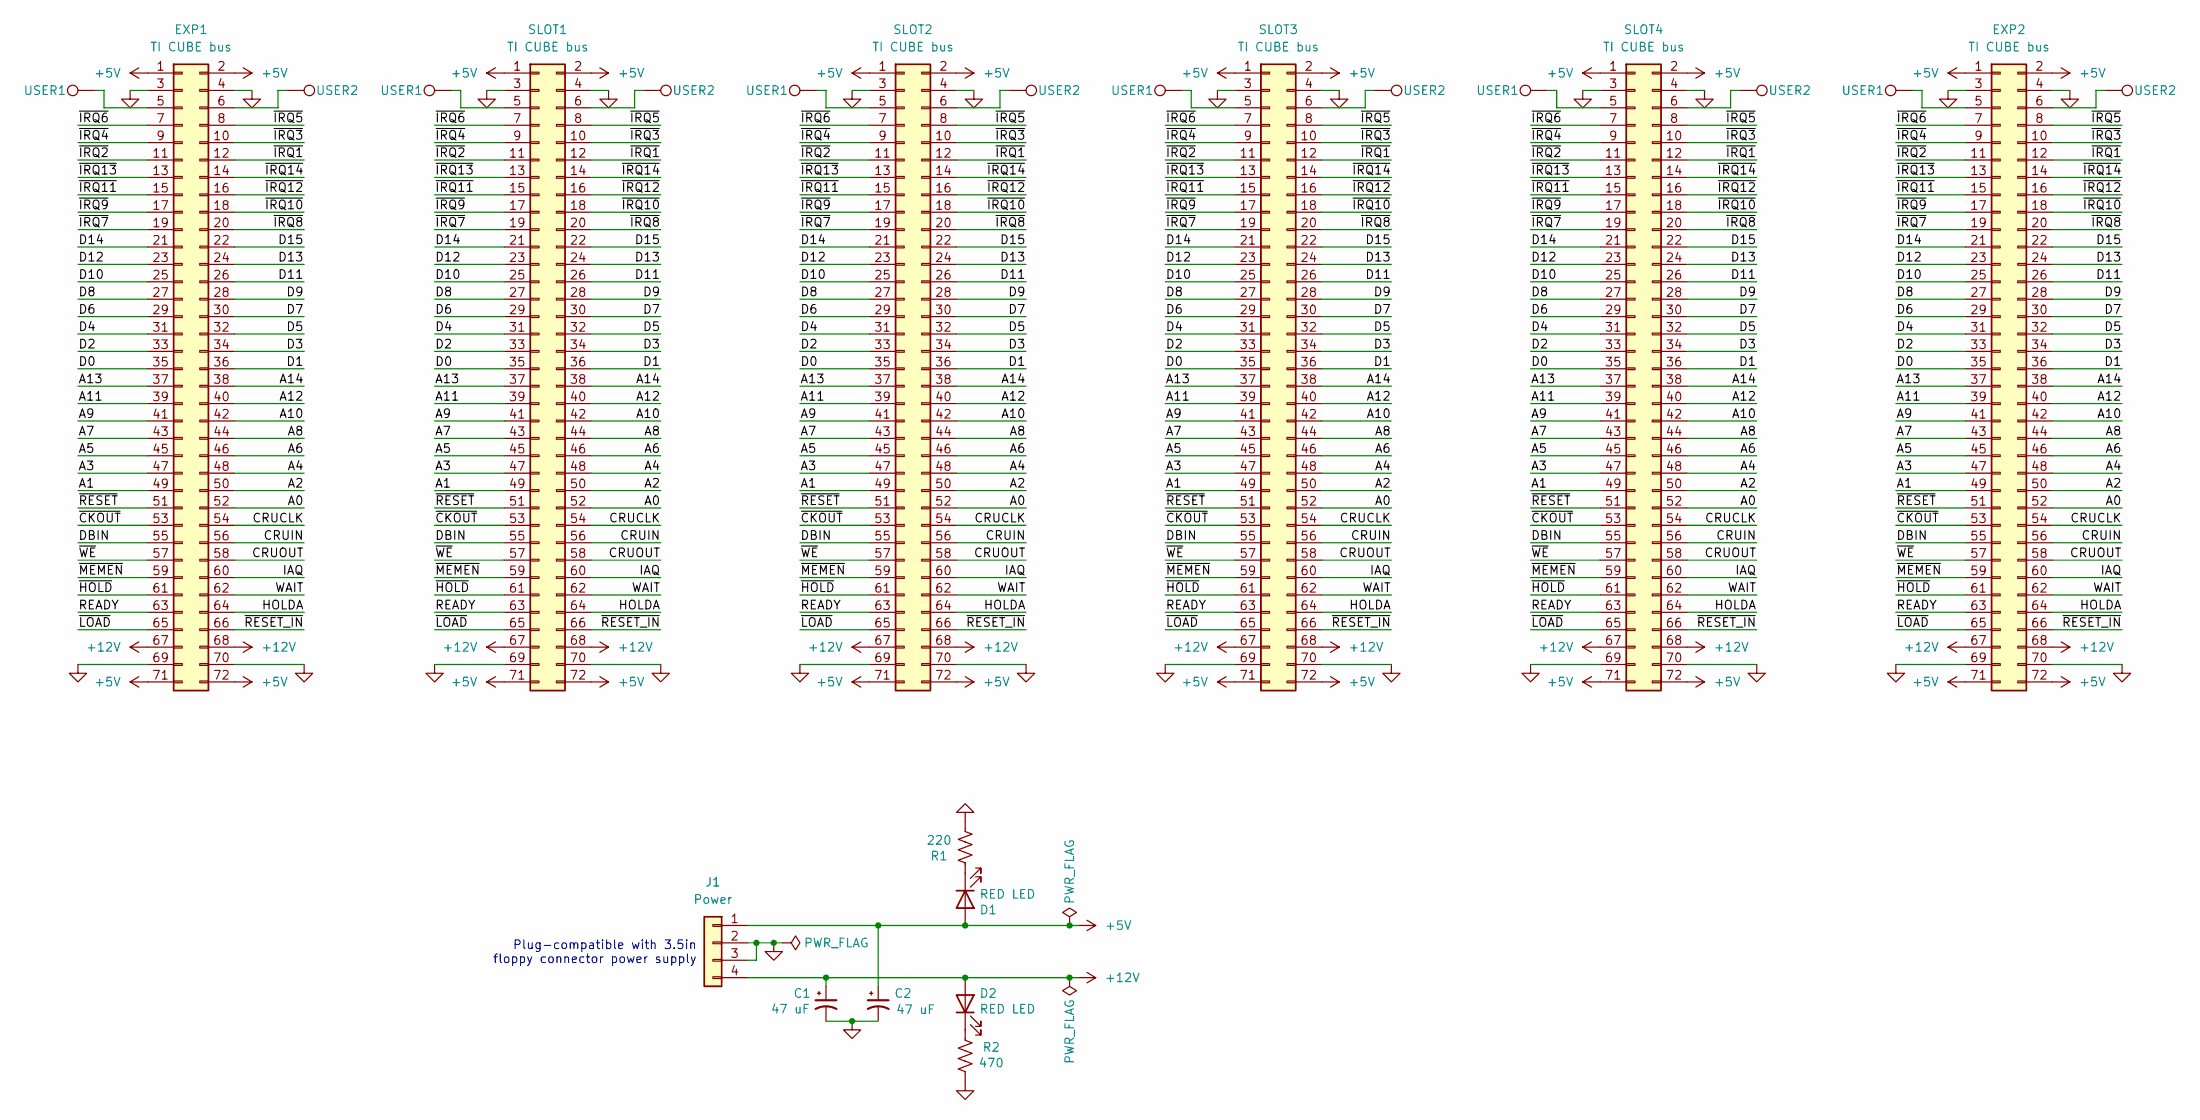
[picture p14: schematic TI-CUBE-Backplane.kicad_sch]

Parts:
C1, C2: 47 uF; CP_Radial_D6.3mm_P2.50mm
D1, D2: RED LED; LED_D3.0mm
EXP1: TI CUBE bus; PinHeader_2x36_P2.54mm_Horizontal
EXP2: TI CUBE bus; PinSocket_2x36_P2.54mm_Horizontal
J1: Power; TE_171825-4
R1: 220; R_Axial_DIN0207_L6.3mm_D2.5mm_P10.16mm_Horizontal
R2: 470; R_Axial_DIN0207_L6.3mm_D2.5mm_P10.16mm_Horizontal
SLOT1, SLOT2, SLOT3, SLOT4: TI CUBE bus; PinSocket_2x36_P2.54mm_Vertical
USER1, USER4, USER5, USER7, USER9, USER11: USER1; TestPoint_THTPad_D1.5mm_Drill0.7mm
USER2, USER3, USER6, USER8, USER10, USER12: USER2; TestPoint_THTPad_D1.5mm_Drill0.7mm

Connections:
+5V: C2.1, D1.2 (A), EXP1.1, EXP1.2, EXP1.71, EXP1.72, EXP2.1, EXP2.2, EXP2.71, EXP2.72, J1.1, SLOT1.1, SLOT1.2, SLOT1.71, SLOT1.72, SLOT2.1, SLOT2.2, SLOT2.71, SLOT2.72, SLOT3.1, SLOT3.2, SLOT3.71, SLOT3.72, SLOT4.1, SLOT4.2, SLOT4.71, SLOT4.72
+12V: C1.1, D2.2 (A), EXP1.67, EXP1.68, EXP2.67, EXP2.68, J1.4, SLOT1.67, SLOT1.68, SLOT2.67, SLOT2.68, SLOT3.67, SLOT3.68, SLOT4.67, SLOT4.68
/A0: EXP1.52, EXP2.52, SLOT1.52, SLOT2.52, SLOT3.52, SLOT4.52
/A1: EXP1.49, EXP2.49, SLOT1.49, SLOT2.49, SLOT3.49, SLOT4.49
/A2: EXP1.50, EXP2.50, SLOT1.50, SLOT2.50, SLOT3.50, SLOT4.50
/A3: EXP1.47, EXP2.47, SLOT1.47, SLOT2.47, SLOT3.47, SLOT4.47
/A4: EXP1.48, EXP2.48, SLOT1.48, SLOT2.48, SLOT3.48, SLOT4.48
/A5: EXP1.45, EXP2.45, SLOT1.45, SLOT2.45, SLOT3.45, SLOT4.45
/A6: EXP1.46, EXP2.46, SLOT1.46, SLOT2.46, SLOT3.46, SLOT4.46
/A7: EXP1.43, EXP2.43, SLOT1.43, SLOT2.43, SLOT3.43, SLOT4.43
/A8: EXP1.44, EXP2.44, SLOT1.44, SLOT2.44, SLOT3.44, SLOT4.44
/A9: EXP1.41, EXP2.41, SLOT1.41, SLOT2.41, SLOT3.41, SLOT4.41
/A10: EXP1.42, EXP2.42, SLOT1.42, SLOT2.42, SLOT3.42, SLOT4.42
/A11: EXP1.39, EXP2.39, SLOT1.39, SLOT2.39, SLOT3.39, SLOT4.39
/A12: EXP1.40, EXP2.40, SLOT1.40, SLOT2.40, SLOT3.40, SLOT4.40
/A13: EXP1.37, EXP2.37, SLOT1.37, SLOT2.37, SLOT3.37, SLOT4.37
/A14: EXP1.38, EXP2.38, SLOT1.38, SLOT2.38, SLOT3.38, SLOT4.38
/CRUCLK: EXP1.54, EXP2.54, SLOT1.54, SLOT2.54, SLOT3.54, SLOT4.54
/CRUIN: EXP1.56, EXP2.56, SLOT1.56, SLOT2.56, SLOT3.56, SLOT4.56
/CRUOUT: EXP1.58, EXP2.58, SLOT1.58, SLOT2.58, SLOT3.58, SLOT4.58
/D0: EXP1.35, EXP2.35, SLOT1.35, SLOT2.35, SLOT3.35, SLOT4.35
/D1: EXP1.36, EXP2.36, SLOT1.36, SLOT2.36, SLOT3.36, SLOT4.36
/D2: EXP1.33, EXP2.33, SLOT1.33, SLOT2.33, SLOT3.33, SLOT4.33
/D3: EXP1.34, EXP2.34, SLOT1.34, SLOT2.34, SLOT3.34, SLOT4.34
/D4: EXP1.31, EXP2.31, SLOT1.31, SLOT2.31, SLOT3.31, SLOT4.31
/D5: EXP1.32, EXP2.32, SLOT1.32, SLOT2.32, SLOT3.32, SLOT4.32
/D6: EXP1.29, EXP2.29, SLOT1.29, SLOT2.29, SLOT3.29, SLOT4.29
/D7: EXP1.30, EXP2.30, SLOT1.30, SLOT2.30, SLOT3.30, SLOT4.30
/D8: EXP1.27, EXP2.27, SLOT1.27, SLOT2.27, SLOT3.27, SLOT4.27
/D9: EXP1.28, EXP2.28, SLOT1.28, SLOT2.28, SLOT3.28, SLOT4.28
/D10: EXP1.25, EXP2.25, SLOT1.25, SLOT2.25, SLOT3.25, SLOT4.25
/D11: EXP1.26, EXP2.26, SLOT1.26, SLOT2.26, SLOT3.26, SLOT4.26
/D12: EXP1.23, EXP2.23, SLOT1.23, SLOT2.23, SLOT3.23, SLOT4.23
/D13: EXP1.24, EXP2.24, SLOT1.24, SLOT2.24, SLOT3.24, SLOT4.24
/D14: EXP1.21, EXP2.21, SLOT1.21, SLOT2.21, SLOT3.21, SLOT4.21
/D15: EXP1.22, EXP2.22, SLOT1.22, SLOT2.22, SLOT3.22, SLOT4.22
/DBIN: EXP1.55, EXP2.55, SLOT1.55, SLOT2.55, SLOT3.55, SLOT4.55
/HOLDA: EXP1.64, EXP2.64, SLOT1.64, SLOT2.64, SLOT3.64, SLOT4.64
/IAQ: EXP1.60, EXP2.60, SLOT1.60, SLOT2.60, SLOT3.60, SLOT4.60
/READY: EXP1.63, EXP2.63, SLOT1.63, SLOT2.63, SLOT3.63, SLOT4.63
/WAIT: EXP1.62, EXP2.62, SLOT1.62, SLOT2.62, SLOT3.62, SLOT4.62
/~CKOUT: EXP1.53, EXP2.53, SLOT1.53, SLOT2.53, SLOT3.53, SLOT4.53
/~HOLD: EXP1.61, EXP2.61, SLOT1.61, SLOT2.61, SLOT3.61, SLOT4.61
/~IRQ1: EXP1.12, EXP2.12, SLOT1.12, SLOT2.12, SLOT3.12, SLOT4.12
/~IRQ2: EXP1.11, EXP2.11, SLOT1.11, SLOT2.11, SLOT3.11, SLOT4.11
/~IRQ3: EXP1.10, EXP2.10, SLOT1.10, SLOT2.10, SLOT3.10, SLOT4.10
/~IRQ4: EXP1.9, EXP2.9, SLOT1.9, SLOT2.9, SLOT3.9, SLOT4.9
/~IRQ5: EXP1.8, EXP2.8, SLOT1.8, SLOT2.8, SLOT3.8, SLOT4.8
/~IRQ6: EXP1.7, EXP2.7, SLOT1.7, SLOT2.7, SLOT3.7, SLOT4.7
/~IRQ7: EXP1.19, EXP2.19, SLOT1.19, SLOT2.19, SLOT3.19, SLOT4.19
/~IRQ8: EXP1.20, EXP2.20, SLOT1.20, SLOT2.20, SLOT3.20, SLOT4.20
/~IRQ9: EXP1.17, EXP2.17, SLOT1.17, SLOT2.17, SLOT3.17, SLOT4.17
/~IRQ10: EXP1.18, EXP2.18, SLOT1.18, SLOT2.18, SLOT3.18, SLOT4.18
/~IRQ11: EXP1.15, EXP2.15, SLOT1.15, SLOT2.15, SLOT3.15, SLOT4.15
/~IRQ12: EXP1.16, EXP2.16, SLOT1.16, SLOT2.16, SLOT3.16, SLOT4.16
/~IRQ13: EXP1.13, EXP2.13, SLOT1.13, SLOT2.13, SLOT3.13, SLOT4.13
/~IRQ14: EXP1.14, EXP2.14, SLOT1.14, SLOT2.14, SLOT3.14, SLOT4.14
/~LOAD: EXP1.65, EXP2.65, SLOT1.65, SLOT2.65, SLOT3.65, SLOT4.65
/~MEMEN: EXP1.59, EXP2.59, SLOT1.59, SLOT2.59, SLOT3.59, SLOT4.59
/~RESET_IN: EXP1.66, EXP2.66, SLOT1.66, SLOT2.66, SLOT3.66, SLOT4.66
/~RESET: EXP1.51, EXP2.51, SLOT1.51, SLOT2.51, SLOT3.51, SLOT4.51
/~WE: EXP1.57, EXP2.57, SLOT1.57, SLOT2.57, SLOT3.57, SLOT4.57
GND: C1.2, C2.2, EXP1.3, EXP1.4, EXP1.69, EXP1.70, EXP2.3, EXP2.4, EXP2.69, EXP2.70, J1.2, J1.3, R1.1, R2.1, SLOT1.3, SLOT1.4, SLOT1.69, SLOT1.70, SLOT2.3, SLOT2.4, SLOT2.69, SLOT2.70, SLOT3.3, SLOT3.4, SLOT3.69, SLOT3.70, SLOT4.3, SLOT4.4, SLOT4.69, SLOT4.70
unnamed: D1.1 (K), R1.2
unnamed: D2.1 (K), R2.2
unnamed: EXP1.5, USER1.1
unnamed: EXP1.6, USER2.1
unnamed: EXP2.5, USER11.1
unnamed: EXP2.6, USER12.1
unnamed: SLOT1.5, USER4.1
unnamed: SLOT1.6, USER3.1
unnamed: SLOT2.5, USER5.1
unnamed: SLOT2.6, USER6.1
unnamed: SLOT3.5, USER7.1
unnamed: SLOT3.6, USER8.1
unnamed: SLOT4.5, USER9.1
unnamed: SLOT4.6, USER10.1

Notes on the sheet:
Plug-compatible with 3.5in floppy connector power supply

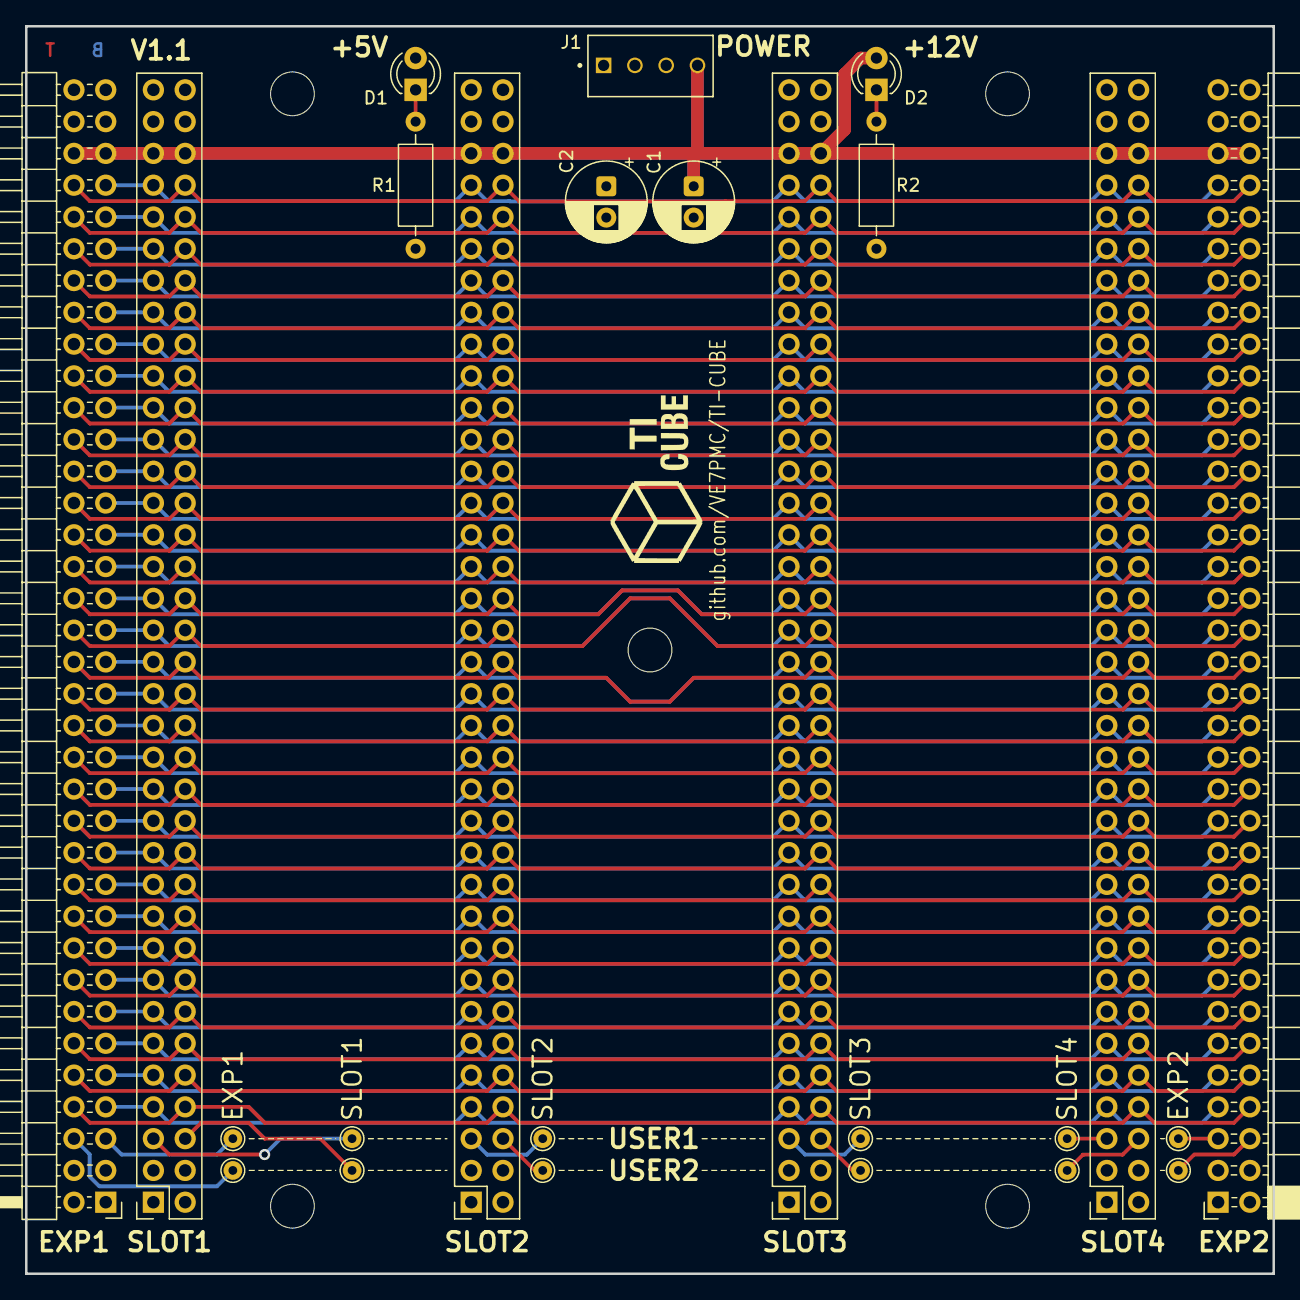
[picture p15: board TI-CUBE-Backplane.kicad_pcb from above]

Board: 4 copper layers, 99.7 x 99.7 mm, 25 parts (0 on the bottom side), 77 nets.
